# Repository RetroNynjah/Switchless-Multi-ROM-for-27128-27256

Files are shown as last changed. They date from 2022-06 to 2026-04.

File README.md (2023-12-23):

# Switchless Multi-ROM for 27128 & 27256 ROMs

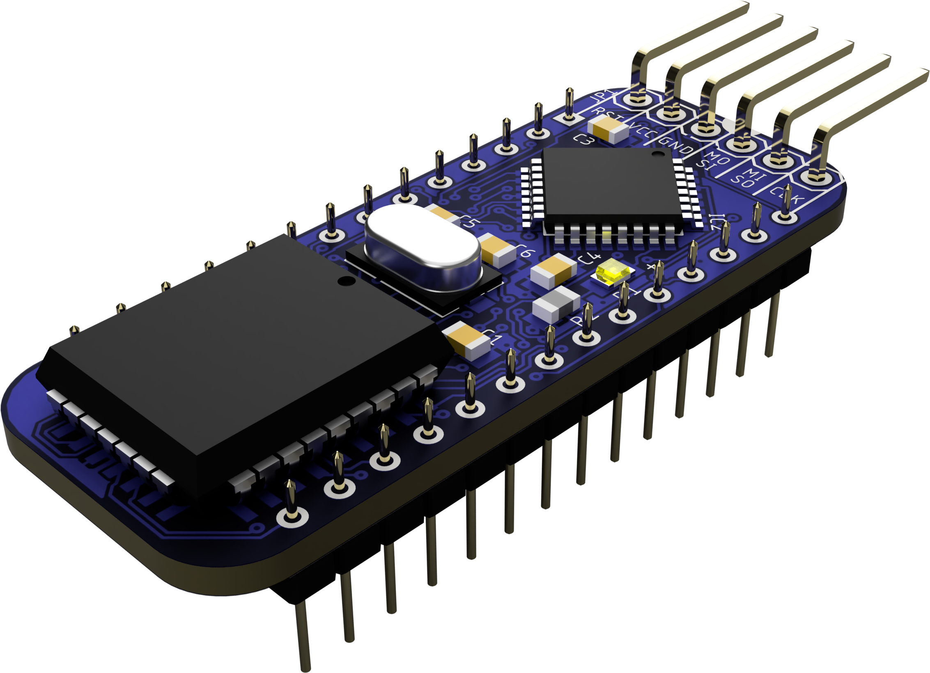
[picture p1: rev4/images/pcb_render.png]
3D rendering
<br/>

A switchless multi-ROM for 27128 and 27256 ROM (28-pin) type applications. The switch is controlled by an MCU that is picking up predefined magic words on the data bus.  
This is a more generic and further developed version of my previous 1541-II Multi-ROM design.

Example use cases:
* ROM switch for Commodore disk drives controlled by DOS commands.
* Menu driven Kernal switch for Commodore C64 (shortboards), Commodore C128 and Commodore TED series.
* You tell me

Check the Applications folder for examples on how to use it for the use cases above.

Check the Technical Guide for a general technical description, build instructions and BOM.

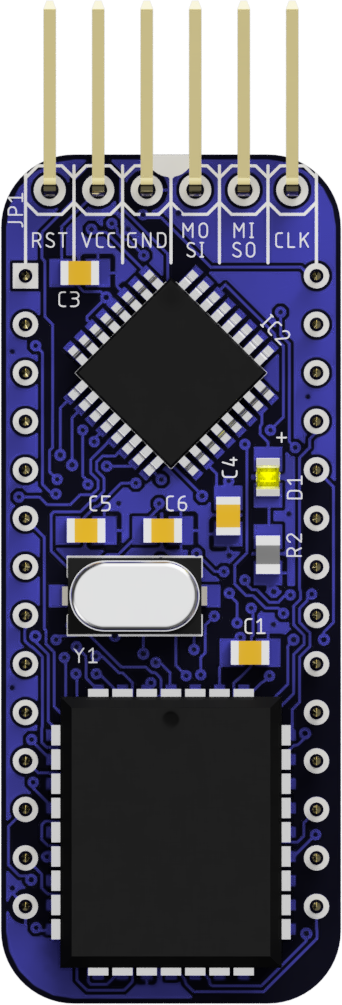
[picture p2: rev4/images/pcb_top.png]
Rendered top view
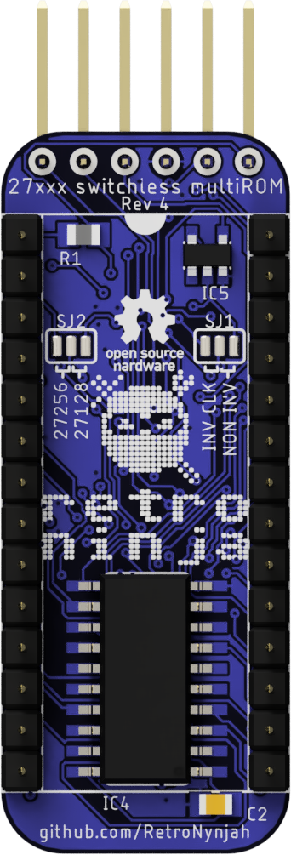
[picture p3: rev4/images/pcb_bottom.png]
Rendered bottom view
  <br/>

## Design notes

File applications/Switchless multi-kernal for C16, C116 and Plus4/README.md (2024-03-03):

# Switchless multi-kernal for Commodore Plus/4 and C16

Can be used as a Kernal switch for the Commodore Plus/4 and C16. It hasn't been tested but could possibly work with the C116 too. 
The Kernal menu is activated by holding the reset switch for a few seconds and then releasing it.

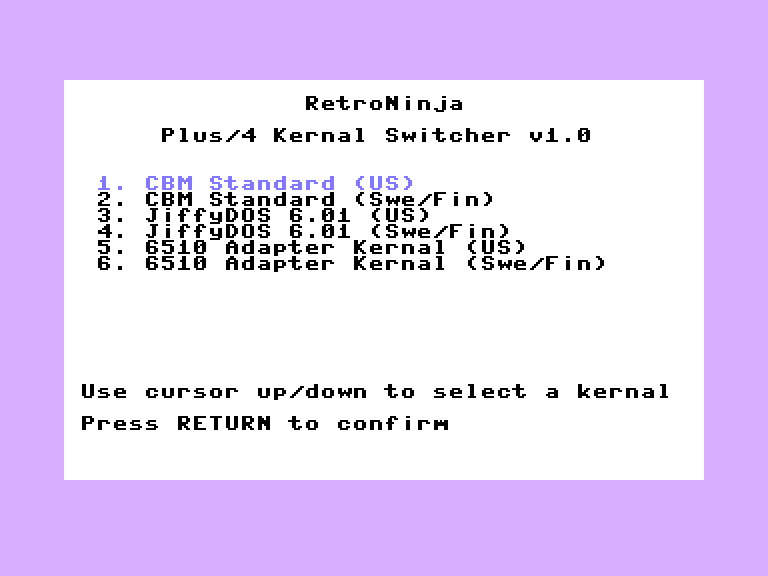
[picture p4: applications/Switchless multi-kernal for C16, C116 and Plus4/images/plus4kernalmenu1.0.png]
Plus/4 Kernal menu screenshot
<br/>

Read more in the User's Guide

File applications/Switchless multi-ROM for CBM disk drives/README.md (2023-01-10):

# Switchless multi-ROM for CBM 1541-II, 1571 and 1581
Switches DOS ROM on Commodore IEC drives that uses 27128/27256 ROMs.  
Can be used to switch ROM between CBM DOS/JiffyDOS/SpeedDOS/DolphinDOS and so on.  
Has been tested in 1541-II, 1571, 1581 and Enhancer 2000 but should work in other 1-2MHz drives with 28-pin ROM.

The switch is controlled by sending a command like *LOAD "2@RNROM",8* from the computer to switch to drive ROM image 2.  
Using a JiffyDOS Kernal a command like *@2@RNROM* can also be used.

Read more in the User's guide.

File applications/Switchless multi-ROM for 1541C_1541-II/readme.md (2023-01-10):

The contents of this folder has been moved to https://github.com/RetroNynjah/Switchless-Multi-ROM-for-27128-27256/tree/main/applications/Switchless%20multi-ROM%20for%20CBM%20disk%20drives

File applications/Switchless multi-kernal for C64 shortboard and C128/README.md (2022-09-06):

# Switchless multi-kernal for C64 shortboard and C128

Can be used as a Kernal switch for the C64 shortboard motherboards and the C128. It has not been tested with C128CR/DCR but works well ion C128/C128D.
The Kernal menu is activated by pressing the RESTORE key for a few seconds (CBM+RESTORE for C64 part Kernal switch in a C128/C128D).

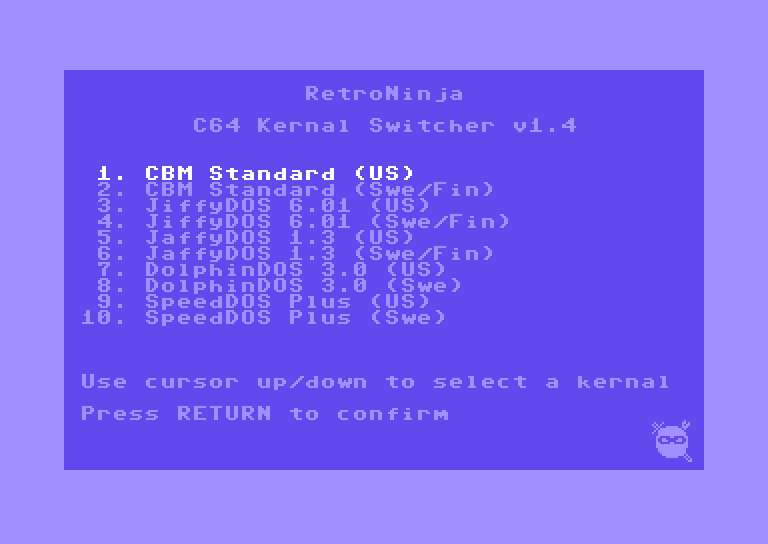
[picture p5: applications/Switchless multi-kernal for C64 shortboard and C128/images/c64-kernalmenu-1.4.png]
C64 Kernal menu
<br/>
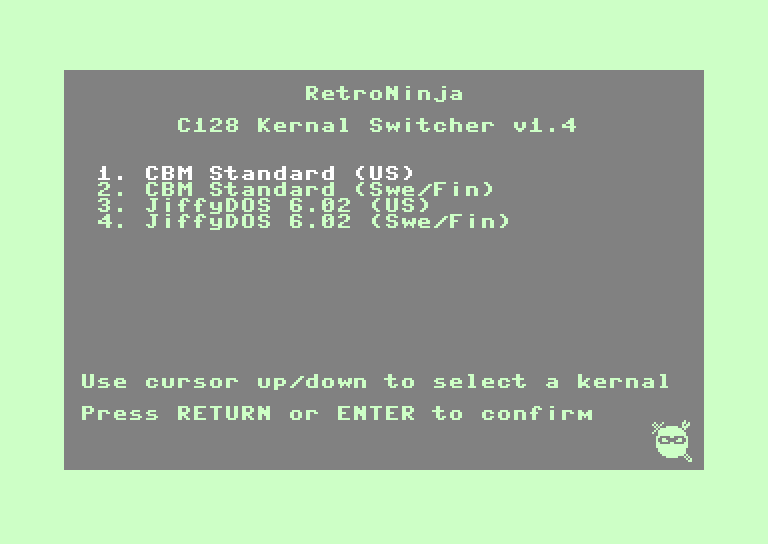
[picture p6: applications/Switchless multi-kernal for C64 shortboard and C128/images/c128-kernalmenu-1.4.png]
C128 Kernal menu
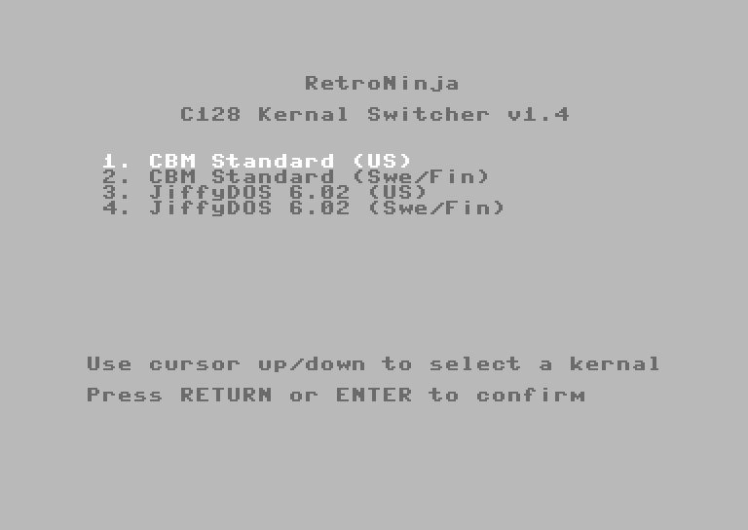
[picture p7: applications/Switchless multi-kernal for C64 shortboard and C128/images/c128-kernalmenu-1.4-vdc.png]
C128 VDC Kernal menu
<br/>

Read more in the User's Guide

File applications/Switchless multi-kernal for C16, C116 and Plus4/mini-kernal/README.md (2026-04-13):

# Plus/4 Mini-Kernal

This is the assembly source code for the C16/C116/Plus4 mini-Kernal.
The projects were created in CBM prg Studio. It needs to be built specifically for PAL or NTSC systems although it has only been tested with PAL systems.

You need to adjust the menu to fit your needs and compile the Mini-Kernals yourself unless you are going with the exact same Kernals I did.

## Disclaimer:  
I'm not an assembly programmer which you should be able to tell by looking at the source. If the code doesn't work for you feel free to fix it,
If anyone wants to have a go at improving and optimizing the code you are free to do so too.

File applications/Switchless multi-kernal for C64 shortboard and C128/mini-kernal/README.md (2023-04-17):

# C64 and C128 Mini-Kernals

This is the assembly source code for the C64 and C128 Mini-Kernals.
The projects were created in CBM prg Studio. They should work with both PAL and NTSC systems although only the C128 version has been tested with NTSC.

You need to adjust the menu to fit your needs and compile the Mini-Kernals yourself unless you are going with the exact same Kernals I did.

## Disclaimer:  
I'm not an assembly programmer which you should be able to tell by looking at the source. If the code doesn't work for you feel free to fix it,
If anyone wants to have a go at improving and optimizing the code you are free to do so too.

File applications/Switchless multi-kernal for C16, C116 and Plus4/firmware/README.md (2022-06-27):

# Firmware

The firmware directories contains source code along with some precompiled hex files for the microcontroller.

The source code is written using the Arduino environment and can be flashed directly from Arduino using an ISP programmer.

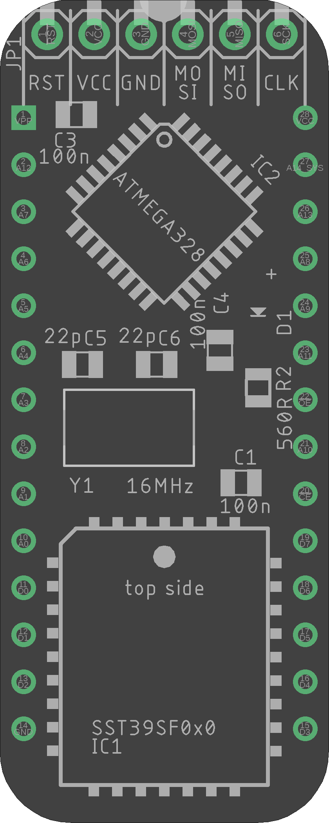
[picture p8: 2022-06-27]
rev4/images/place-top-crop.png

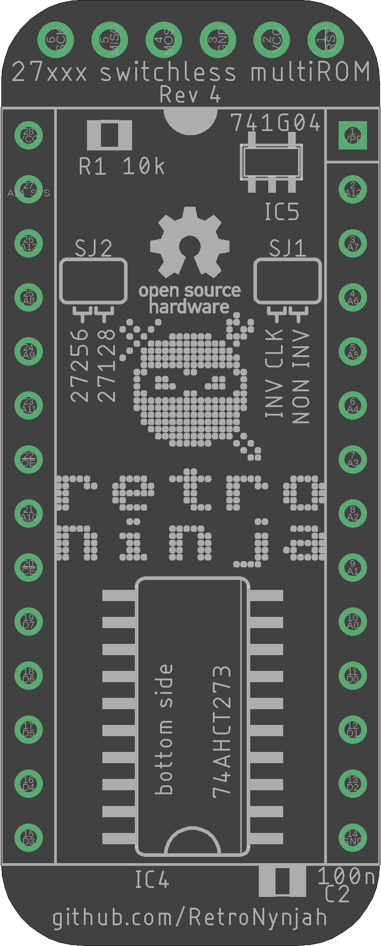
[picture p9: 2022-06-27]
rev4/images/place-bottom-crop.png

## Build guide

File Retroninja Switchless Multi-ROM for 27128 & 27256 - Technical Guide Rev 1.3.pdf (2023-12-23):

# Retroninja Switchless Multi-ROM for 27128

& 27256

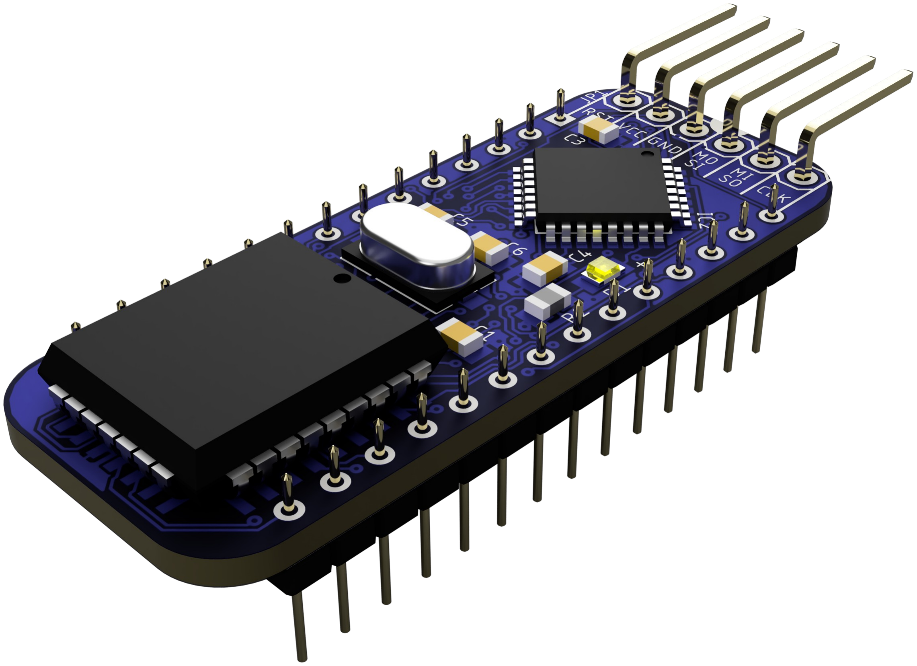
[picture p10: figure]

# Technical Guide

Retroninja Switchless Multi-ROM for 27128 & 27256 | Technical Guide Version 1.3

## Table of Contents

# Background

I first created this ROM switcher as a DOS ROM switcher for the Commodore 1541-II disk drive which uses a 27128 compatible ROM. The space in the 1541-II is very limited. That's why the module is so small and has to use SMD components.
I realized that it can be used for a lot of other equipment that is using similar ROMs so it was re-branded and upgraded to support switching 27256 ROM images too.

# Theory of operation

The circuit is meant to sit in a ROM socket instead of a 28-pin 27128/27256 ROM.
The AVR microcontroller (MCU) is connected to the data pins of the ROM socket through a flip-flop that latches the data to give the MCU more time to read the data. It's also connected to some header pins that can be connected to a clock source, a reset line and optionally other signals. It also has an on-board flash chip that contains multiple ROM images.
With the help of an external clock source, the MCU can capture bytes that are passing on the data bus and react to a predefined string of ”magic bytes” by switching the upper address pins on the flash circuit to switch to a different ROM image.
The flip-flop triggers on positive-edge of clock and if data is arriving on the bus at the negative edge of the clock signal then the clock source needs to be inverted for the flip-flop to latch the data correctly. This can be done by installing the inverter gate at IC5 and configuring solder jumper SJ1 for inverted clock.
The need for this differs between implementations depending on how the magic bytes ends up on the bus. The module has two modes: 27128 and 27256 mode. The mode is selected using a solder jumper. In 27128 mode the A14 address pin on the flash chip is controlled by the MCU giving the MCU five address pins (A14-A18) to use which gives a maximum of 32*16KByte ROMs. In 27256 mode the A14 pin is controlled by the host system leaving four address pins (A15-A18) to the MCU which gives a maximum of 16*32KByte ROMs. An onboard LED can be used for diagnostic blinking or other feedback.

# Usage examples

The two use cases I've used it in is for switching JiffyDOS ROM in Commodore disk drives and Kernal in the Commodore 8-bit computers but it should be usable for other things too.

Commodore 1541-II/1571/1581 DOS ROM Switcher
The MCU source code for the 1541-II/1571/1581 ROM switch can be found under applications in the GitHub repository: https://github.com/RetroNynjah/Switchless-Multi-ROM-for-27128-27256
At power on, the MCU in the ROM switcher reads address 0 from its internal EPROM to find out which ROM it should select, sets the A14-A18 (or A15-A18) address pins on the flash chip accordingly and resets the drive to make sure it’s booted with the correct image. This can be noticed when the drive is powered on and the drive initializes and stops spinning and then spins up again briefly during the switch reset.
It then starts listening for a switch command.
Even at a clock speed of 20 MHz, reading and analyzing data on a 1-2MHz data bus can be quite a challenge so the data on the drive data bus is buffered in the switcher by a 74AHCT273 flip-flop that is clocked by the Write signal on the 6502 MPU in the drive. By clocking the data with the R/W signal we filter out irrelevant bus traffic and the flip-flop holds the relevant data until the next R/W cycle. This gives the MCU a little more time to read the data from the flip-flop.

The MCU listens for a predefined sequence of bytes in reverse order (MORNR@) and once the sequence is found, it treats the following numeric character as the target ROM image number. The reverse order of the characters on the bus is why the image number must be specified at the beginning of the command.
The MCU sets address pins A14-A18 (or A15-A18) on the flash chip according to image selection and it stores the ROM number at address 0 of its internal EPROM for use at next power-on. It then resets the drive by toggling the reset line.
The command can be sent from basic on a computer such as C64 or C128 by utilizing any disk drive command that contains text strings such as:

If the computer is equipped with JiffyDOS and the correct drive has been selected using CTRL-D or similar, DOS wedge commands can be used for switching ROM:

The commands in the above examples will return a file not found error but you should see the drive switch ROM and perform a drive reset and turn of the error LED. The ROM switch LED will blink 2 times to indicate that image 2 was selected.
When building a 1541-II ROM switch you should bridge the solder jumpers like this:
SJ1
Inverted Clock | Non-inverted Clock

Note: To invert clock we must also install IC5

SJ2
27256 | 27128

And for a 1571 and 1581 ROM switch the solder jumpers should be configured like this: SJ1
Inverted Clock | Non-inverted Clock

Note: To invert clock we must also install IC5

SJ2
27256 | 27128

Some pins on the switch needs to be connected to the right signals in the drive. These signals can be connected to the drive using test clips but to have a secure installation it's better to solder the cables to the bottom of the PCB.

LOAD “2@RNROM”,8

@2@RNROM

Switch pin | Drive signal
CLK | R/W (6502 pin 34)
MOSI | RESET (Middle pin of IEC DIN connector)

This switch only suits the 1541-II/1571/1581 and clones that has 28-pin ROM sockets.
1541 drives and some of it's clones have 24-pin 2364 type ROMs and I have another Multi-ROM version that is compatible with those in the following repository: https://github.com/RetroNynjah/Switchless-Multi-ROM-for-2364

Commodore 64 shortboard/C128/TED series menu-driven Kernal switch
The MCU source code and Mini-Kernal source code for the C64 shortboard/C128 kernal switch can be found under samples in the GitHub repository at: https://github.com/RetroNynjah/Switchless-Multi-ROM-for-27128-27256
At power on, the MCU in the Kernal switch reads address 0 from its internal EPROM to find out which Kernal it should select, sets the A14-A18 (or A15-A18) address pins on the flash chip accordingly and resets the drive to make sure it’s booted with the correct image.
If at any time, restore is pressed and held for a few seconds the MCU will detect this and switch to Kernal 0 which is a menu Kernal. The C16/116/Plus4 menu is activated by holding RESET for a few seconds and then releasing it.
For this application I created custom Mini-Kernals for the C64, the C128 and the C16/C116/Plus4 that display lists of Kernals to choose from.

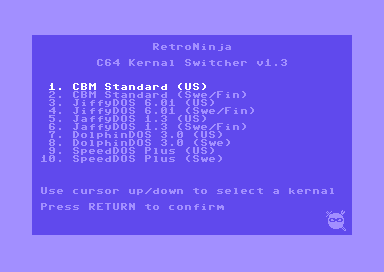
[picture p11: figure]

When the user selects a Kernal image from the menu, the Mini-Kernal writes a predefined switching command to RAM along with a byte that indicates the selected image number. It does this over and over. Example of the command: RNROM64#1, RNROM128#1 or RNROM+4#1 where 1 is a byte with value 0x01 that tells the switch that we want to switch to kernal image 1.
The Kernal switch now captures the command from the data bus, writes the selected kernal number to the MCU EPROM for future use, then it switches the address pins A14/A15-A18 accordingly. It then pulls the reset line briefly to make the computer restart using the new Kernal. The computer will continue to start up using this Kernal until a new choice is made.
Having different commands for the platforms makes it possible to equip both the ROM sockets in a Commodore 128 (not CR/DCR) with Kernal switches and keep them separated.

In this case both switches will trigger their menus when RESTORE is held as the MCUs don't know if they are being addressed or not. The MCUs will switch back to the previous image if they detect that a reset is being performed by something other than themselves.
To activate the C64 switch menu in a C128 you hold the CBM key together with RESTORE. When selecting an image from the C64 kernal menu you hold CBM while you press RETURN to make it boot into C64 mode with the new Kernal.
The C128CR/DCR doesn't have a separate ROM for the C64 part and doesn't need an separate switch for C64 mode but it needs to have the C64 Basic and Kernal images bundled in the same flash ROM as the C128 Kernals. This switch will switches Kernals for both C64 mode and C128 mode at the same time. This can be both good or bad depending on how you combine your Kernals.
It also needs to have the Mini-Kernals modified so that both Mini-Kernals uses the same switching
command such as RNROMDCR#1 and have an MCU firmware compatible with 27256 switching.
For the C128, the flash is populated with a 16 KB C128 Mini-Kernal followed by up to 31*16 KB Kernals (good luck finding more than a couple).

For the C64, the flash is populated with a 16 KB combination of 8 KB basic ROM and 8 KB Mini-Kernal followed by up to 31*16 KB Basic+Kernal combinations.
Here's an example ROM layout for a C64 shortboard or the C64 Kernal in the C128 that fits an SST39SF010A:

Example for a C128 with an SST39SF010A:

Example for a C128CR/DCR with an SST39SF010A:

As both C64 mode and C128 mode Kernals are in the same ROM a larger flash chip may be needed to accommodate all Kernals. If you have more C64 Kernals than C128 Kernals you still need to fill the vacant C128 slots with working Kernals such as a stock CBM Kernal or you will never be able to start the C128 into C64 mode either.
When building a C64/C128/TED-series Kernal switch you should bridge the solder jumpers like this:
SJ1
Inverted Clock | Non-inverted Clock

Note: As we don't invert the clock we don't need to install IC5 either

SJ2 (all except CR/DCR)
27256 | 27128

SJ2 (C128CR/DCR)
27256 | 27128
C64 Basic | 64 Mini | 128 Mini | C64 Basic | 64 CBM krnl | 128 CBM krnl | C64 Basic | 64 Jiffy US | 128 Jiffy US | C64 Basic | 64 Jiffy SE | 128 Jiffy SE
8kB | 8kB | | 8kB | 8kB | | 8kB | 8kB | | 8kB | 8kB
16kB | | 16kB | 16kB | | 16kB | 16kB | | 16kB | 16kB | | 16kB
Mini-Kernal | CBM Kernal | JiffyDOS US | JiffyDOS SE | JiffyDOS DK | Mini-Kernal | Mini-Kernal | Mini-Kernal
16kB | 16kB | 16kB | 16kB | 16kB | 16kB | 16kB | 16kB
Basic | Mini-Kernal | Basic | CBM Kernal | Basic | JiffyDOS US | Basic | JiffyDOS SE | Basic | JiffyDOS DK | Basic | JaffyDOS | Basic | DolphinDOS | Basic | SpeedDOS
8kB | 8kB | 8kB | 8kB | 8kB | 8kB | 8kB | 8kB | 8kB | 8kB | 8kB | 8kB | 8kB | 8kB | 8kB | 8kB
16kB | | 16kB | | 16kB | | 16kB | | 16kB | | 16kB | | 16kB | | 16kB

Some pins on the switch needs to be connected to the right signals in the computer. These signals can be connected to various ICs in the computer using test clips but to have a secure installation it's better to solder the cables to vias on the PCB. See pictures in the samples directory of the GitHub repository.
Switch pin | Computer signal | Comments
CLK | R/W
MISO | RESTORE | Only on C64/C128
MOSI | RESET

When building a Kernal switch for the Plus/4 (or C116) you will need to keep the profile low by using the flat kind of headers that are usually sold as “Stackable Arduino headers”.

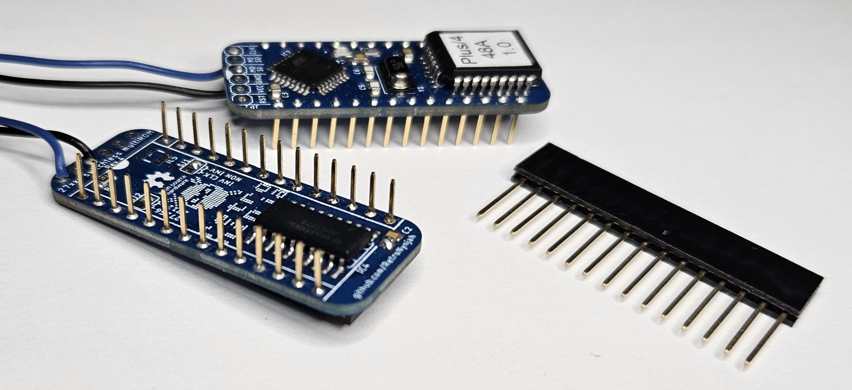
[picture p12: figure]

Optionally you can remove the Kernal socket and solder the switch directly to the motherboard using any kind of header.
This switch when configured as a C64 Kernal switch fits the C64 shortboard (PCB 250469) and the C64 part of the C128. C64 longboards have 24-pin 2364 type Kernal ROMs and I have another Multi-ROM version that is compatible with those in the following repository: https://github.com/RetroNynjah/Switchless-Multi-ROM-for-2364

# Assembling the module

The PCB is small and a bit difficult to solder but it can be hand soldered. The reason for the small size is space constraints in the Commodore 1541-II disk drives that this PCB was initially designed for. Other drives such as 1571 and 1581 have the same constraints.
The flash chip (PLCC) is the trickiest part to solder and I recommended reflow soldering the top side using stencil and solder paste. Then solder the bottom side by hand and finally solder the pin headers.
There are two solder jumpers on the bottom that must be configured.
If you configure SJ1 for inverted clock then you must also install IC5. Otherwise you can leave it out. It will only be used when SJ1 is configured for inverted clock.
Note: Don't forget to program the flash before soldering!

# Parts

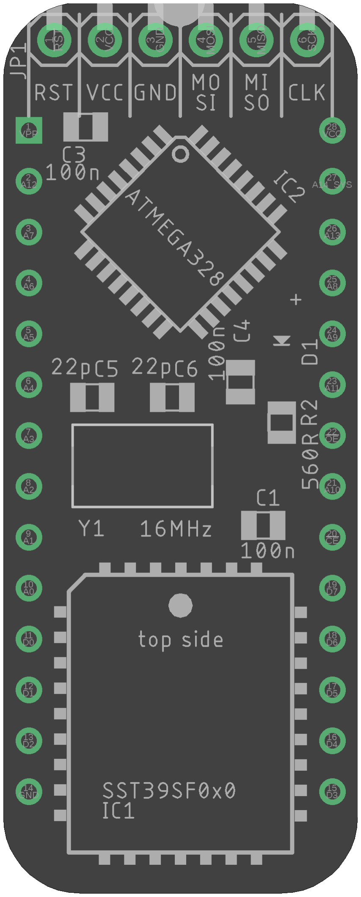
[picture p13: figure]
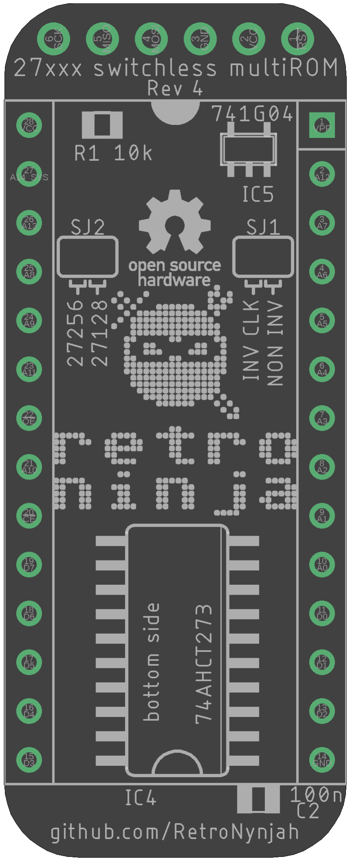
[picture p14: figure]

Top side is to the left, bottom side is to the right.
Component | Part | Description | Comment
JP1 | Header | 6-pin right-angle
D1 | LED | 0805 LED
C1, C2, C3,C4 | 100nF capacitor | 0805 ceramic
C5, C6 | 30pF capacitor | 0805 ceramic | 22pF works fine too
Y1 | ECS-200-20-3X-TR | 20MHz Crystal | 16MHz is ok for 1MHz systems
R1 | 10kΩ resistor | 0805 Resistor
R2 | 560Ω resistor | 0805 Resistor
IC1 | SST39SF0x0 | 32-PLCC Flash 4.5-5.5V | SST39SF010/20/40
IC2 | ATmega MCU | 32-TQFP MCU | Atmega48/88/168/328
IC3 | Headers | 2 header rows, 14 pin | Use machined or flat pins - not square
IC4 | 74AHCT273 | 20-SOIC 5.3mm Flip-Flop
IC5 | 741G04 | SOT23-5 1 x Inverter | Only needed if clock needs inverting
The ATmega model is not critical. The firmware requires less than 2KB of MCU flash. I have tested Atmega48, 48A, 48PA, 48PB, 88A, 328P and they have worked for me. Any other pin-compatible ATmega could work too depending on your application but it must be able to run at 20MHz if you are going to use it in a 2MHz system such as 1571/1581. For 1MHz systems it is enough with 16MHz.

# Programming the microcontroller

The firmware can be flashed using the 6-pin ISP header. The source code is written for Arduino and programming the firmware can be done directly from the Arduino IDE using an ISP programmer.
If you are using an Atmega328 it can be programmed as an Arduino UNO. The other variants require custom board definitions. I recommend the DIY AVR cores that can be installed using the Arduino Boards Manager (https://github.com/sleemanj/optiboot).
If you can't or don't want to use Arduino I have some pre-compiled hex files for the Kernal switch and drive ROM switch along with fuse configurations and syntax examples for how to program them using avrdude. These can be found under the Applications folder in my GitHub repository.

# Programming the flash chip (ROM)

The flash chip needs to be programmed before soldering it. If you need to reprogram the flash later it must first be de-soldered and then re-soldered again after reprogramming.
You need to concatenate all your images into one file and fill up any empty space in flash with valid extra images to avoid bricking your host device if an incorrect image number is selected. If that would happen the EPROM can be reset by re-flashing the firmware.
In 27128 mode all images should be 16KB and in 27256 mode all the images need to be 32KB.

# Document revision history

1.0 Initial version
1.1 BOM Corrected
1.2 Updated BOM with 20MHz crystal, changed AVR core and added information about 1571 & 1581 1.3 Updated kernal switch section with C16, C116 and Plus/4

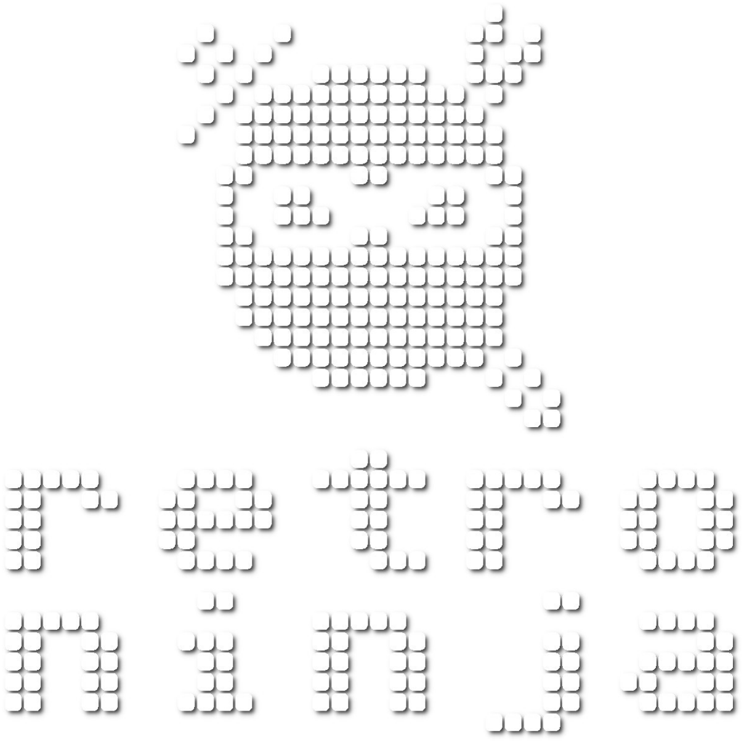
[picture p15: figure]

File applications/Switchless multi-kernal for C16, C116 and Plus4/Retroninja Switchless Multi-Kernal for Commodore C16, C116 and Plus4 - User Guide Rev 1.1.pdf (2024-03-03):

# Retroninja Switchless Multi-Kernal for Commodore C16, C116 & Plus/4


# User Guide

Retroninja Switchless Multi-Kernal for Commodore C16, C116 & Plus/4

User Guide
Version 1.1

## Table of Contents

# Functional description

At power on, the MCU in the Kernal switch holds the reset line active while it reads address 0 from its internal EPROM to find out which Kernal it should select, sets the A14-A18 address pins on the flash chip accordingly and releases the reset line to make sure the computer is booted using the correct Kernal.
If at any time, reset is pressed and held for a few seconds the MCU will detect this and switch to the first Kernal in ROM (Kernal 0) which is a menu Kernal. For this application I created a custom Mini-Kernal for the C16/C116/Plus4 that displays a list of Kernals to choose from.

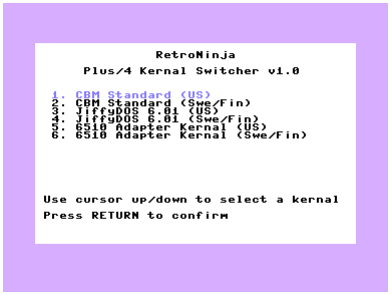
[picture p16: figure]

When the user selects a Kernal image from the menu, the Mini-Kernal writes a predefined switching command to RAM along with a byte that indicates the selected image number. It does this over and over. Example of the command: RNROM+4#1 where 1 is a byte with value 0x01 that tells the switch that we want to switch to Kernal image 1.
The Kernal switch now captures the command from the data bus, writes the selected Kernal number to the MCU EEPROM for future use, then it switches the ROM address pins A13-A18 accordingly. Finally, it resets the computer using the new Kernal by pulling the reset line briefly. The computer will continue to start up using this new Kernal until a new choice is made.
The flash is populated with the Mini-Kernal followed by up to 10*16kB Kernals. It would in theory be possible to add up to 31 Kernals if both the Mini-Kernal and the MCU firmware was modified in some way to accommodate that many Kernal images.
Here's an example layout that fits in an SST39SF010A:
Mini-Kernal | CBM EN | CBM Swe | Jiffy En | Jiffy Swe | 6510 En | 6510 Swe | blank
16kB | 16kB | 16kB | 16kB | 16kB | 16kB | 16kB | 16kB

# Installing the Kernal switch

The switch will replace the Kernal ROM chip (U24 on the Plus/4 or U4 on C16/C116).
Pay attention to the direction of the notch on the chip that indicates the location of pin 1. Pin one on the switch should face the same direction. Pin 1 on the switch is at the end that has a 6-pin header. It is also indicated by a printed notch on the bottom side of the switch.
The switch needs low profile pin headers to fit in the Plus/4 or the socket might need to be removed from the motherboard so the switch can be soldered directly to the board.
The below pins on the switch must be connected to the right signals on the motherboard.
Switch pin | Computer signal | Example of locations
CLK | R/W | 7501/8501 pin 39, 6529 pin 1
MOSI | RESET | 7501/8501 pin 40, 7551/8551 pin 4

The connections can be made on the chips using test clips but it's recommended to solder pin headers to vias on the motherboard where available and connect the pin headers using Dupont wires or solder a cable to the motherboard for a permanent installation. If you want to solder pin headers to the vias you can try inserting them from the top side without taking the board out. Try heating the pins with the soldering iron while pushing them into the via using pliers but to get the best possible connection of the pins they should be soldered from the bottom of the motherboard.
The below pictures show examples of suitable vias for different motherboards.

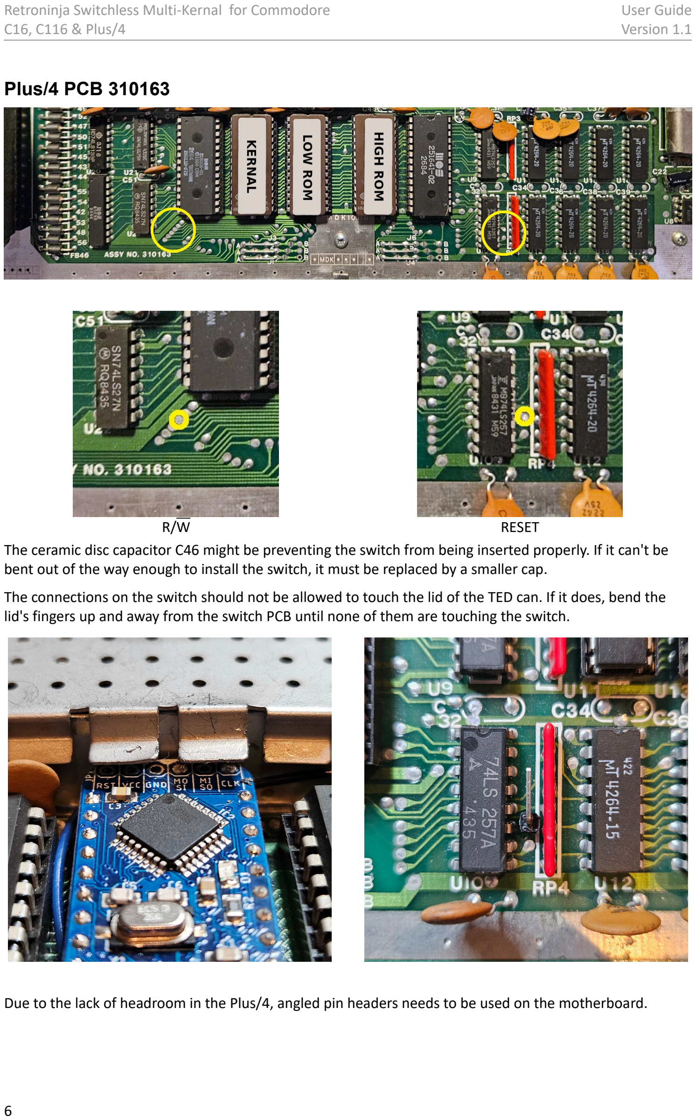
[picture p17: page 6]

Plus/4 PCB 310163

R/W | RESET
The ceramic disc capacitor C46 might be preventing the switch from being inserted properly. If it can't be bent out of the way enough to install the switch, it must be replaced by a smaller cap.
The connections on the switch should not be allowed to touch the lid of the TED can. If it does, bend the lid's fingers up and away from the switch PCB until none of them are touching the switch.

Due to the lack of headroom in the Plus/4, angled pin headers needs to be used on the motherboard.

C16

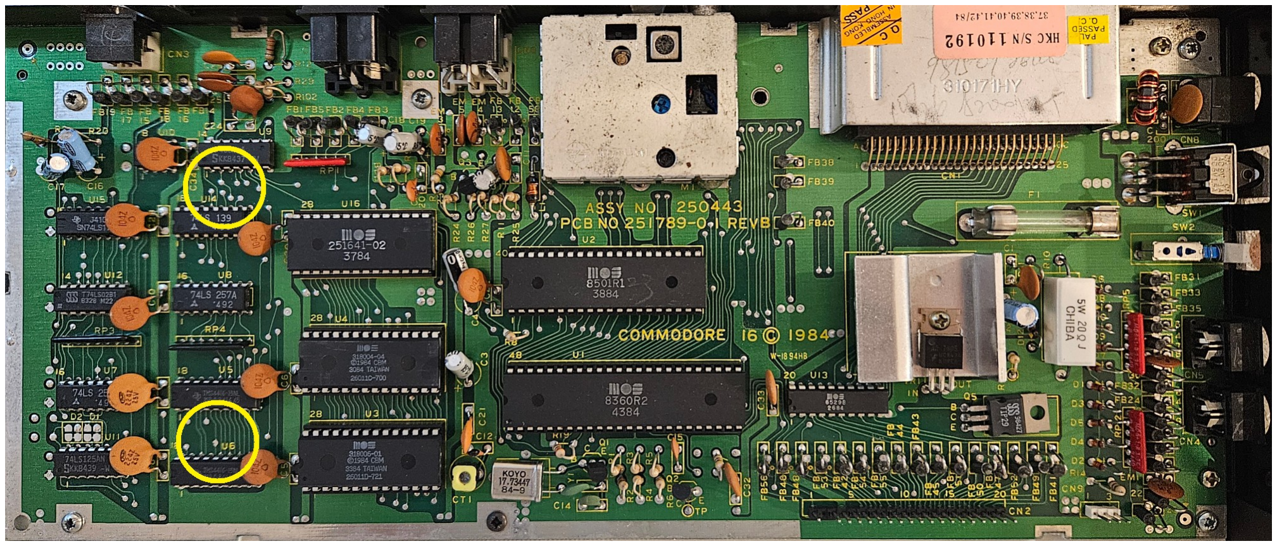
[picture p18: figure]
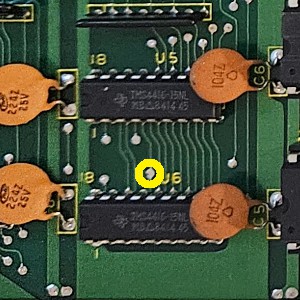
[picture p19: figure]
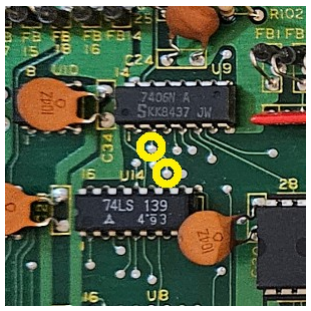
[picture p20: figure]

R/W | RESET

C116
TBD

# Using the Kernal switch

Hold the reset key for about three seconds and then release it to activate the Kernal menu. Once in menu you can use cursor up/down to move to the Kernal you want to switch to and press return. The switch resets the computer with the new Kernal and saves your choice for next power-on.

# Upgrading the firmware

The firmware in the microcontroller can be upgraded using the 6 ISP pins. The source code is written for Arduino and programming the firmware can be done directly from the Arduino IDE using an ISP programmer.

If your device is using an Atmega328 it can be programmed as an Arduino UNO. The other variants require custom board definitions. I have used the Easy DIY AVR cores from https://github.com/sleemanj/optiboot. Board manager URL is
https://raw.githubusercontent.com/sleemanj/optiboot/master/dists/package_gogo_diy_atmega8_series_in dex.json (https://raw.githubusercontent.com/sleemanj/optiboot/master/dists/package_gogo_diy_atmega8_series_index.json)
If you can't or don't want to use Arduino I have some precompiled hex files for the Kernal switch and drive ROM switch along with fuse configurations and syntax examples for how to program them using avrdude. These can be found under the Applications folder in my GitHub repository at: https://github.com/RetroNynjah/Switchless-Multi-ROM-for-27128-27256

# Programming the flash chip (ROM)

The flash chip needs to be programmed before soldering it. If you need to reprogram the flash later it must first be desoldered and then resoldered again after reprogramming.
The flash chip should contain the Mini-Kernal image followed by all switchable kernal images in correct order. All images needs to have a size of exactly 16kB.

# Document revision history

1.0 Initial version
1.1 Added C16 pictures

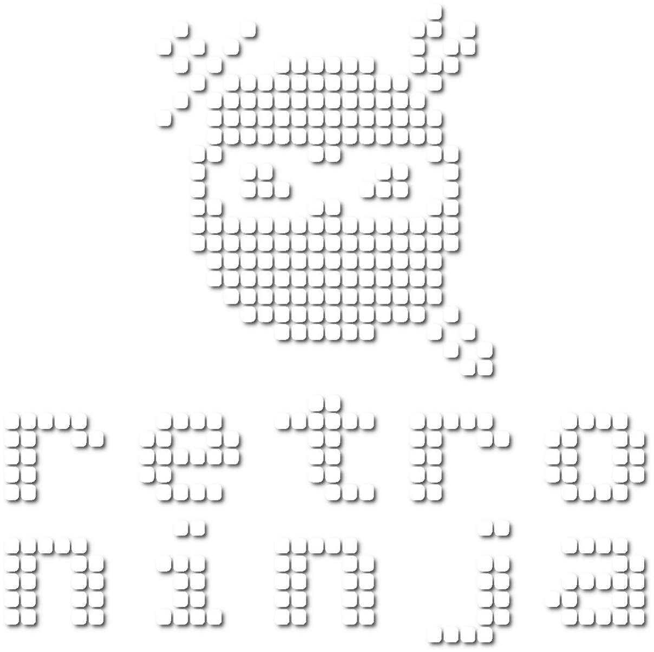
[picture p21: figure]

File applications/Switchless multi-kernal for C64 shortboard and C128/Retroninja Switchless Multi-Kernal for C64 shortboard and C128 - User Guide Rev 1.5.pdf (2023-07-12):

# Retroninja Switchless Multi-Kernal for C64 shortboard and C128

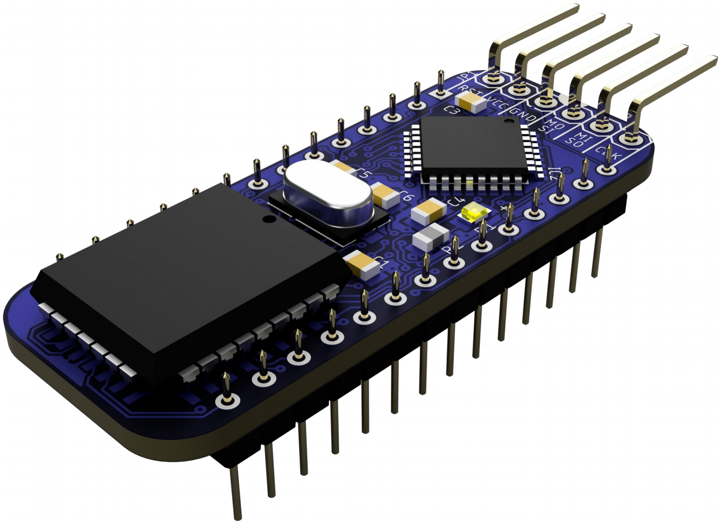
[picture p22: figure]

# User Guide

Retroninja Switchless Multi-Kernal for C64 shortboard and C128

User Guide
Version 1.5

## Table of Contents

# Functional description

At power on, the MCU in the Kernal switch holds the reset line active while it reads address 0 from its internal EPROM to find out which Kernal it should select, sets the A14-A18 address pins on the flash chip accordingly and releases the reset line to make sure the computer is booted using the correct Kernal.
If at any time, restore is pressed and held for a few seconds the MCU will detect this and switch to Kernal 0 which is a menu Kernal. For this application I created custom Mini-Kernals for the C64 and the C128 that displays a list of Kernals to choose from.


When the user selects a Kernal image from the menu, the Mini-Kernal writes a predefined switching command to RAM along with a byte that indicates the selected image number. It does this over and over. Example of the command: RNROM64#1 where 1 is a byte with value 0x01 that tells the switch that we want to switch to kernal image 1.
The Kernal switch now captures the command from the data bus, writes the selected kernal number to the MCU EPROM for future use, then it switches the address pins A14-A18 accordingly. It then resets the computer using the new Kernal by pulling the reset line. The computer will continue to start up using this new Kernal until a new choice is made.
The flash is populated with the Mini-Kernal followed by up to 10*16 KB Kernals. It would in theory be possible to add up to 31 Kernals if both the Mini-Kernal and the MCU firmware was modified in some way to accommodate that many Kernal images.
Here's an example for a C64 layout that fills out an SST39SF010A:

Example for C128 with an SST39SF010A:

Example for C128DCR with an SST39SF010A:

As both C64 mode and C128 mode Kernals are in the same ROM a larger flash chip may be needed to accommodate all Kernals. If you have more C64 Kernals than C128 Kernals you still need to fill the C128 slots with working Kernals such as a stock CBM kernal or you will never be able to start the C128 into C64 mode either.

Basic | Mini-Kernal | Basic | CBM Kernal | Basic | JiffyDOS US | Basic | JiffyDOS SE | Basic | JiffyDOS DK | Basic | JaffyDOS | Basic | DolphinDOS | Basic | SpeedDOS
8kB | 8kB | 8kB | 8kB | 8kB | 8kB | 8kB | 8kB | 8kB | 8kB | 8kB | 8kB | 8kB | 8kB | 8kB | 8kB
16kB | | 16kB | | 16kB | | 16kB | | 16kB | | 16kB | | 16kB | | 16kB
Mini-Kernal | CBM Kernal | JiffyDOS US | JiffyDOS SE | JiffyDOS DK | Mini-Kernal | Mini-Kernal | Mini-Kernal
16kB | 16kB | 16kB | 16kB | 16kB | 16kB | 16kB | 16kB
C64 Basic | 64 Mini | 128 Mini | C64 Basic | 64 CBM krnl | 128 CBM krnl | C64 Basic | 64 Jiffy US | 128 Jiffy US | C64 Basic | 64 Jiffy SE | 128 Jiffy SE
8kB | 8kB | | 8kB | 8kB | | 8kB | 8kB | | 8kB | 8kB
16kB | | 16kB | 16kB | | 16kB | 16kB | | 16kB | 16kB | | 16kB

The C64 version of this Kernal switch only suits the C64 shortboards (PCB 250469) and the C64 part of the C128.
The C128DCR doesn't have a separate ROM for the C64 part and doesn't need an separate switch for C64 mode but it needs a specially combined DCR version of this switch.
C64 longboards have 24-pin 2364 type Kernal ROMs and I have another Multi-ROM version that is compatible with those at:
https://github.com/RetroNynjah/Switchless-Multi-ROM-for-2364

# Installing the Kernal switch

The below pins on the switch must be connected to the right signals on the C64 motherboard.
Switch pin | Computer signal | Example of locations
CLK | R/W | 8500 pin 38, 6526 pin 22
MISO | RESTORE | KBD connector pin 3
MOSI | RESET | 8500 pin 40, 6526 pin 34

The signals can be found at the below places on the C128 motherboard.
Switch pin | Computer signal | Example of locations
CLK | R/W | 8502 pin 39, 8563 pin 9, 6526 pin 22
MISO | RESTORE | KBD connector pin 3, U16 pin 9
MOSI | RESET | 8502 pin 40, 6526 pin 34

The connections can be made on the chips using test clips but it's recommended to solder pin headers to vias on the motherboard and connect to the pin headers using Dupont wires or solder one end of Dupont cables directly to the vias for a permanent installation.
If you want to solder pin headers to the vias you can try inserting them from the top side without taking the board out. Try heating the pins with the soldering iron while pushing them into the via using pliers but to get the best possible connection of the pins they should be soldered from the bottom of the motherboard. The following pages show where the switch should be installed and shows examples of suitable vias for different motherboards.

C64 PCB 250469
The switch will replace Kernal ROM chip named U4 on this board. U4 is normally not socketed and needs to be desoldered from the board and replaced with a socket before the switch is installed.
Pay attention to the notch on the ROM chip U4 indicating pin 1. The socket should have it's notch facing the same direction and the switch should also be installed with pin 1 facing the same direction.
Pin 1 on the switch is at the end that has six header pins. It is also indicated by a printed notch on the bottom side of the board.

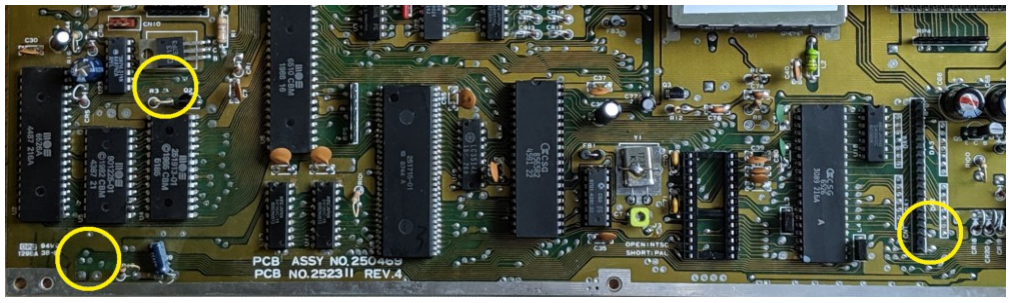
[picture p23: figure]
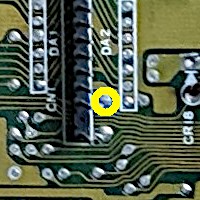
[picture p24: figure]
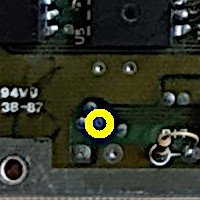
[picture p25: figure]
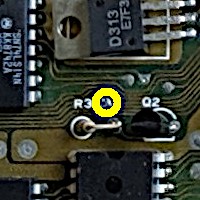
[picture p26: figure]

RESTORE | R/W | RESET

C128/C128D
This board requires two switches. The switch for C128 will replace the C128 Kernal ROM named U35 and the C64 mode switch replaces the C64 Kernal ROM U32.
Pay attention to the notch on the socket that indicates pin 1. Pin 1 on the switch is at the end that has six header pins. It is also indicated by a printed notch on the bottom side of the board.
The R/W signal in the point marked below can be a bit low on some C128s such as the Rev 7 boards and on the C128 Neo. If you can't get the switch to switch kernal after selecting an image (hangs on selection), try connecting to the R/W signal on the 8563 or 8502 instead to see if that makes a difference. See page 6 for connection points.

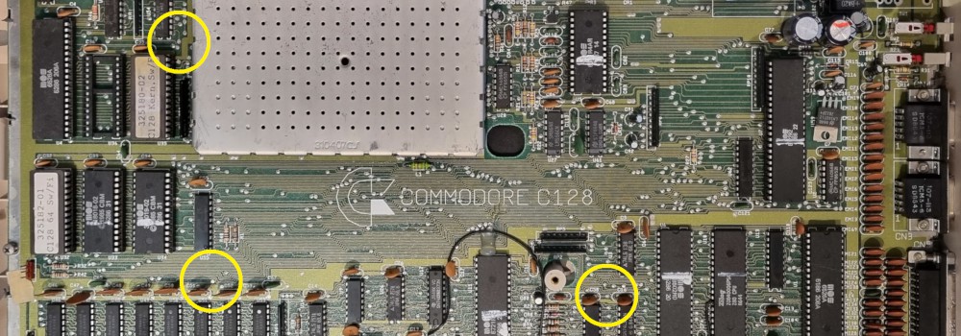
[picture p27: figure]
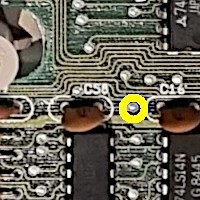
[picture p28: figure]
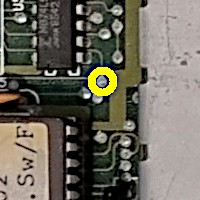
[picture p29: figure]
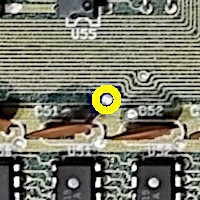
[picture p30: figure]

RESTORE | R/W | RESET

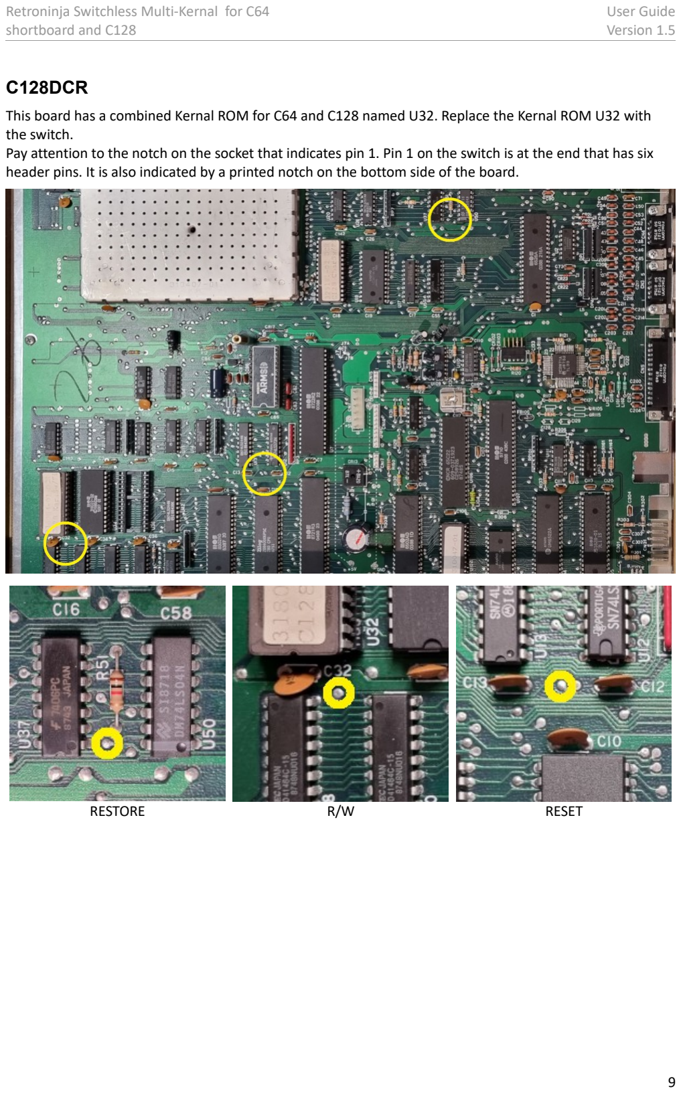
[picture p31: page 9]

C128DCR
This board has a combined Kernal ROM for C64 and C128 named U32. Replace the Kernal ROM U32 with the switch.
Pay attention to the notch on the socket that indicates pin 1. Pin 1 on the switch is at the end that has six header pins. It is also indicated by a printed notch on the bottom side of the board.
RESTORE | R/W | RESET

# Using the Kernal switch

Switching C64 and C128 Kernals
Hold the restore key for about three seconds until the kernal menu is activated. Once in menu you can use cursor up/down to move to the Kernal you want to switch to and press return. The switch resets the computer with the new Kernal and saves your choice for next power-on.

Switching C64 Kernal in a C128
When switching the C64 Kernal in a C128, hold the CBM and restore keys for about three seconds until the C64 kernal menu is activated. Keep holding the CBM key while selecting Kernal with the cursor up/down and return keys. While pressing return you should hold the CBM key until the reset is done to be taken to C64 mode. Otherwise you will end up in C128 mode after switching C64 Kernal and will have to do a GO64 or CBM+reset again.
The switch saves your choice for next power-on.

In the a C128DCR you can use either C128 kernal menu or C64 kernal menu to switch Kernal but both C64 Kernal and C128 Kernal will be switched at the same time.

# Upgrading the firmware

The firmware in the microcontroller can be upgraded using the 6-pin ISP header. The source code is written for Arduino and programming the firmware can be done directly from the Arduino IDE using an ISP programmer.
If your device is using an Atmega328 it can be programmed as an Arduino UNO. The other variants require custom board definitions. I recommend the DIY AVR cores that can be installed using the Arduino Boards Manager (https://github.com/sleemanj/optiboot).
If you can't or don't want to use Arduino there are some precompiled hex files for the Kernal switch and along with fuse configurations and syntax examples for how to program it using avrdude. These can be found under the Applications folder in my GitHub repository at: https://github.com/RetroNynjah/Switchless-Multi-ROM-for-27128-27256

# Programming the flash chip (ROM)

The flash chip needs to be programmed before soldering it. If you need to reprogram the flash later it must first be desoldered and then resoldered again after reprogramming.
The flash chip should contain the Mini-Kernal image followed by all switchable kernal images in correct order. All images needs to have a size of exactly 16KB.

C64
In a C64 switch those 16KB are made up of 8KB Basic + 8KB Kernal.

C128/C128D
In the C128 the C128 kernal is 16KB and it does not have to be paired with a Basic ROM. The C64 ROM in a C128 is the same as the one in a C64 so it needs basic+kernal pairs.

C128CR/C128DCR
In the C128CR/DCR the C128 kernal is 16KB and needs to be paired with the C64 Basic and C64 Kernal. As the switch will switch both C64 and C128 kernal at the same time you will have to pay extra attention to how you mix the images to not get a confusing setup.

# Document revision history

1.0 Initial version
1.1 Document title corrected
1.2 C128DCR pictures added and minor adjustments
1.3 Added information about Kernal ROM locations and sockets 1.4 Added information about R/W on C128
1.5 Expanded information about R/W problems on C128

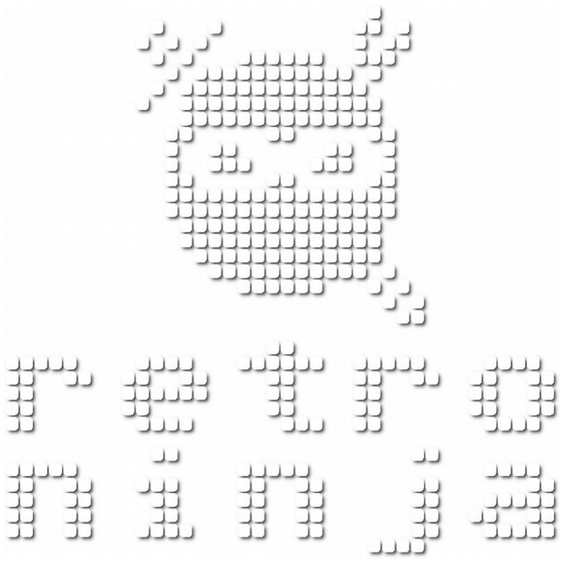
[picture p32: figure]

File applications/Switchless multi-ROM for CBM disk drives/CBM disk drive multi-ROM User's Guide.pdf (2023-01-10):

# Switchless Multi-ROM for CBM 1541-II, 1571 & 1581 User’s Guide

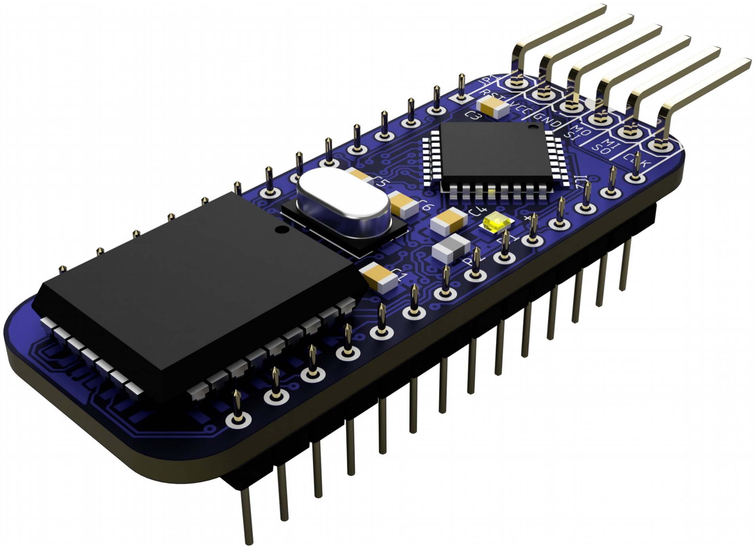
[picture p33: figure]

This microcontroller-based switchless ROM-switcher for the 1541-II, 1571 and 1581 disk drives lets you switch drive ROM between stock CBM DOS and JiffyDOS or other DOS version using simple basic commands. It's based on the switchless multi-ROM for 27128/27256 ROMs. Read more about it at: https://github.com/RetroNynjah/Switchless-Multi-ROM-for-27128-27256

## Usage

The switcher is listening to the data bus for a predefined word and a number. The easiest way to send the word to the drive is to issue a load command to the drive from basic with the word as filename or to utilize a JiffyDOS wedge command.
The default magic word is #@RNROM where # is the number of the ROM image you want to switch to.
LOAD “1@RNROM”,8 switches drive 8 to DOS image 1 and LOAD “2@RNROM”,8 switches to image 2 and so on. The default valid range of numbers is 1-4.
The drive will respond with a file not found error but the programmer will pick up the command, blink the multi-ROM LED to indicate which image was selected, switch the ROM by setting the high address pins accordingly and reset the drive using the newly selected ROM.
The selected ROM will be remembered and used at power-on.
If you have a JiffyDOS kernal in your computer you can select the right device using CTRL+D and issue the following commands instead: @1@RNROM or @2@RNROM
P a g e 1 | 5

Retroninja 1541-II switchless multi-ROM | User’s Guide version 1.2

## Theory of operation

At power on, the microcontroller in the ROM switcher reads address 0 from its internal EPROM to find out which ROM it should select, sets the address A14-A16 or A15-A16 on the flash chip depending on ROM size and then resets the drive to make sure it’s booted with the correct image. This can be noticed when the drive is powered on and the drive initializes and stops spinning and then spins up again briefly during the switch reset.
It then starts listening for a switch command.
Even at a clock speed of 20 MHz, reading and analyzing a 1-2MHz data bus can be a challenge so the data on the 1541-II data bus is buffered in the switch by a 74AHCT273 flip-flop that is clocked by the Write signal on the 6502 MPU in the disk drive. By clocking the data with the R/W signal we filter out irrelevant bus traffic and the flip-flop holds the data until the next write cycle. This gives the microcontroller enough time to read the data from the flip-flop.
The microcontroller listens for a predefined sequence of bytes in reverse order (MORNR@) and once the sequence is found, it treats the following numeric character as the target ROM image number. The reverse order of the characters on the bus is why the image number must be specified at the beginning of the command.
The microcontroller sets address pins A14-A16 or A15-A16 on the flash chip according to image selection and it stores the ROM number at address 0 of its internal EPROM for use at next power-on. It then resets the drive by toggling the IEC reset line.

## Building the circuit

The switcher is small and a bit difficult to solder but it can be hand soldered. The reason for the small size is space constraints in many disk drives such as the 1541-II, 1571 and 1581.
The Flash chip is the trickiest part to solder and I recommend reflow soldering of the top side using stencil and solder paste. Then solder the bottom side by hand and finally solder the pin headers.

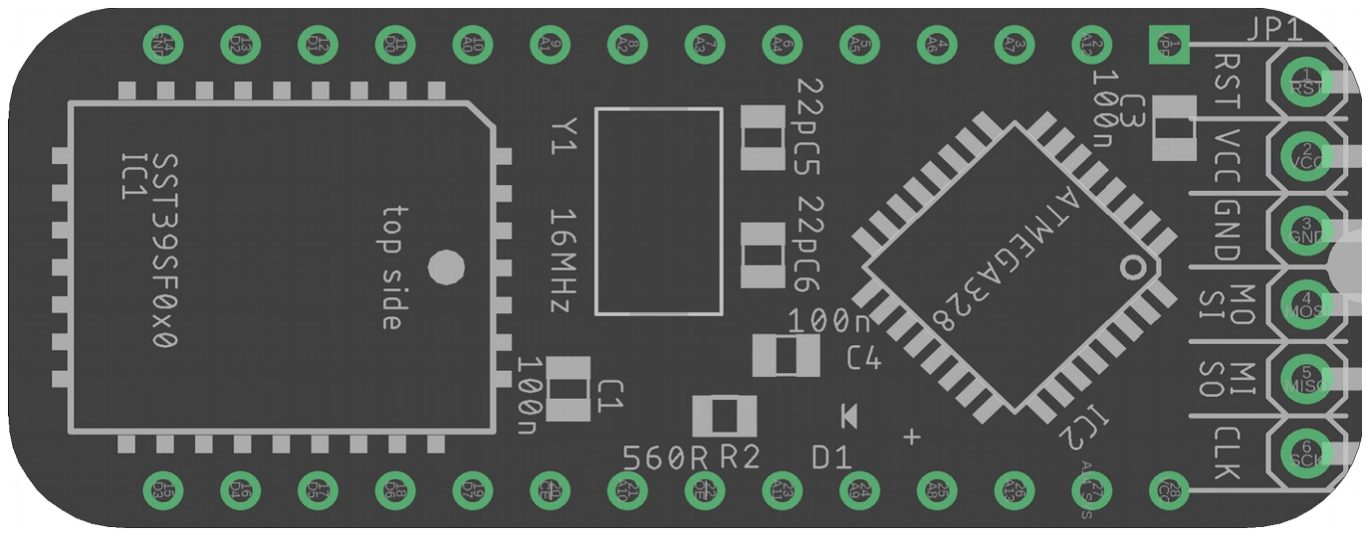
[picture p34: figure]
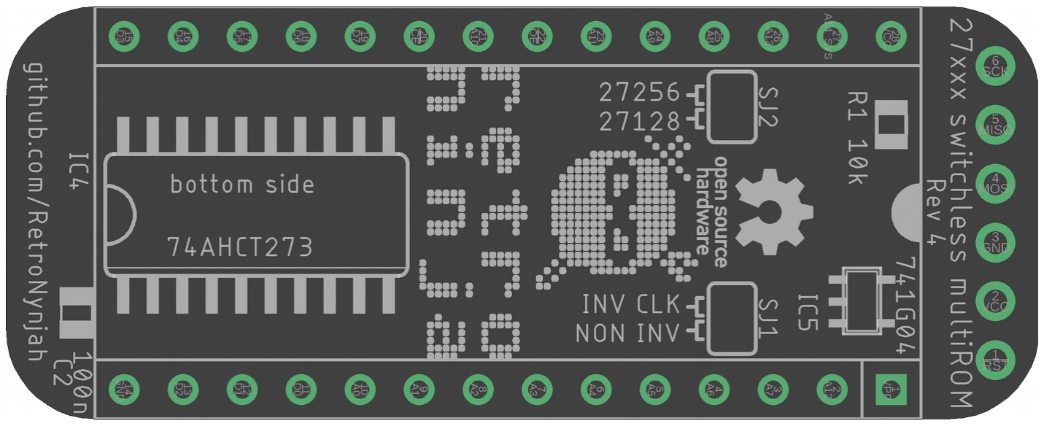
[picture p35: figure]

P a g e 2 | 5

### Parts

The switcher is designed for the SST39SF010A flash chip but the bigger SST39SF020/SST39SF040 could be used too if no SST39SF010A is available. Remember to duplicate the flash contents to fill all of flash to prevent floating pins from switching to empty flash areas.
The microcontroller can be pretty much any variation of ATmega48/88/168/328 as long as it can run at 20MHz.
The flip-flop needs to be a 74AHCT273. LS/HCT/AHC or any other variant will most likely not work. The 74AHCT1G04 single gate inverter is needed for inverting the active low write signal from the 6502 to the active high clock input of the flip-flop.
The recommended crystal is a 20 MHz crystal (for 1571/1581) but a 16MHz works for 1541-II.
The LED on the board is optional but flashes a number of times indicating the number of the selected ROM when switching. It is only there for debugging reasons.
The pin headers that goes into the ROM socket should have round machined pins or be of that long flat stackable type that is used for the pass-through pin headers on Arduino shields. The flat ones are recommended as the profile gets even lower with those headers. There is almost no headroom in the 1541-II, 1571 and 1581 external drives. The internal drives in the 128D models have more room. Square pin headers destroy the ROM socket in the drive so don't use those.

### Programming the microcontroller

The code for the controller was created using the Arduino environment and the device can be programmed in circuit from a sketch in the Arduino IDE using an ISP programmer.
I recommend the DIY AVR cores that can be installed using the Arduino Boards Manager (https://github.com/sleemanj/optiboot).
If you can't or don't want to use Arduino there are some precompiled hex files for the Kernal switch and along with fuse configurations and syntax examples for how to program it using avrdude. These can be found under the Applications folder in my GitHub repository at https://github.com/RetroNynjah/Switchless-Multi-ROM-for-27128-27256
How to use an Arduino as ISP or how to use an ISP programmer such as a USBASP will not covered by this document.
The firmware can also be programmed using AVRDUDE and the pre-compiled HEX file or using the popular TL866II programmer. The pin-out of the programming pins on the PCB matches the pin-out of the TL866II ICSP connector so a straight 6-pin cable can be used.

### Programming the flash chip

Due to space constraints, there are no on-board programming headers for the flash chip so the flash chip must be programmed in a flash/EPROM programmer before soldering it to the board or desoldered for reprogramming.
It could also be possible to make a programming adapter to put on top of the flash chip to program it while it’s still soldered to the board but this is not tested.
The ROM chip in the 1541-II is only 128 kbit (16 kilobyte) and the 1571/1581 drive ROMs are 256kbit (32 kilobyte) while the flash chip is 1 Mbit (128 kilobyte). It’s highly recommended to fill the entire flash chip with working DOS images to prevent bricking of the drive by selecting a non-existing image. The switcher will not work without a working ROM in the drive that can receive the serial data and
P a g e 3 | 5

put it on the data bus.
If you just use two ROM images, fill the flash with the same two images over and over for safety.

## Installation

The circuit can be installed in the drive without soldering by using DuPont cables with test clips that attaches to the R/W pin on the 6502 MPU and to the reset pin on the back of any of the IEC connectors. However, it is recommended to solder the cables to the pins on the bottom of the drive PCB. That makes for a much more robust and transportable solution.
An even more stable solution is to solder the cables to the edge of the switcher PCB instead of using a pin header but that could make it harder to upgrade the firmware in the future.
The edge of the Multi-ROM PCB with the six ISP pins should face the notched end of the ROM socket (Pin 1).

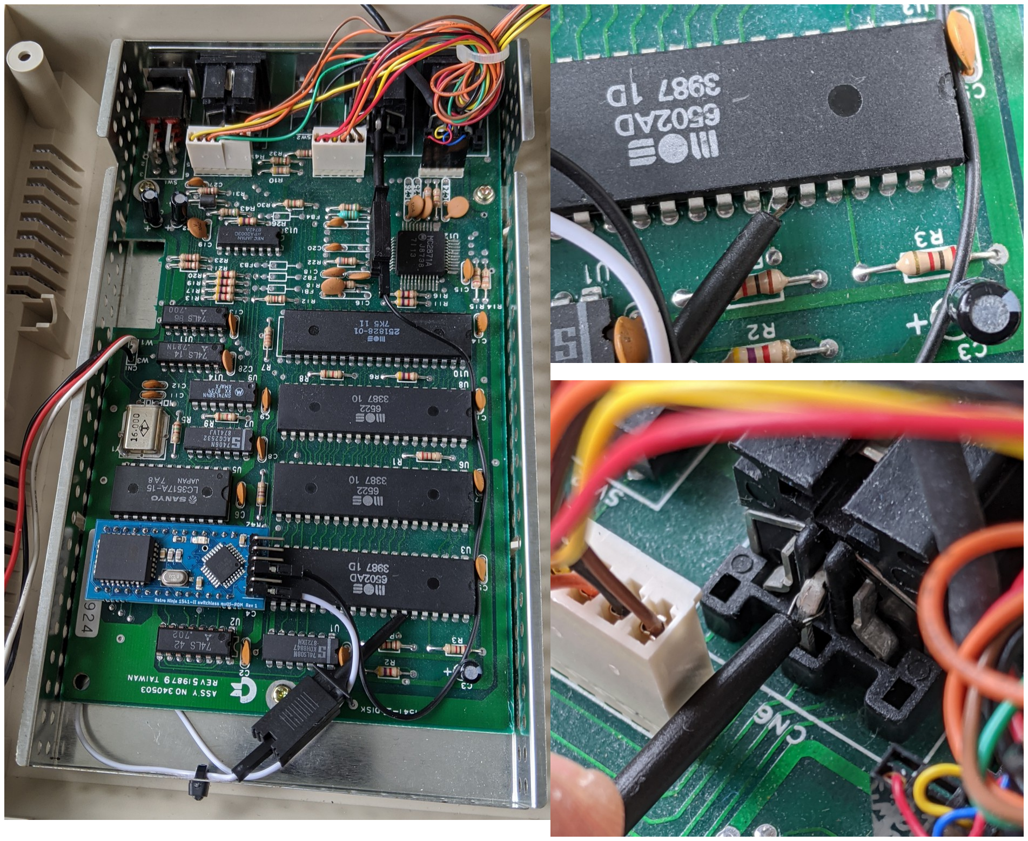
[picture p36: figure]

The clock signal (CLK on the Multi-ROM) connects to the R/W pin (pin 34) on the 6502 MPU.
MOSI on the Multi-ROM connects to IEC reset. That’s the center pin on the back of the IEC connectors. The Multi-ROM works without a connection to IEC reset but a manual drive reset would then be needed after switching ROM.
The sketch and a pre-compiled firmware for the Multi-ROM can be found in the Applications directory in the repository at:
https://github.com/RetroNynjah/Switchless-Multi-ROM-for-27128-27256
P a g e 4 | 5

## Troubleshooting

If the device becomes bricked due to an incorrect DOS image, program the ATmega with a sketch that sets byte 0 to 0x00 or 0xFF in the internal EPROM. Then upload the original Multi-ROM sketch again and you should be back on track.
You can also set byte 0 of the EEPROM to 0x00 using AVRDUDE or using the Minipro software. Switching will not work if you are some fast loaders such as Action Replay in your computer. Try switching the ROM without the fast loader. Switching ROM using JiffyDOS in the C64 is working fine though.
The switcher work in other CBM compatible drives that are using 27128 or 27256 ROMs. The Enhancer 2000 has been tested and works but unfortunately there's just not space enough in the OC-118 drive.

## Change history

This is the change history for the user’s guide.
For changes to the schematics, PCB or firmware, please refer to the GitHub repository at https://github.com/RetroNynjah/Switchless-Multi-ROM-for-27128-27256
Date | Version | Description
2021-05-15 | 1 | Initial version
2021-05-22 | 1.1 | Alternative ATmega MCUs
2023-01-10 | 1.2 | Major update. Now supports 1571/1581. Updated recommendations for crystals and microcontrollers

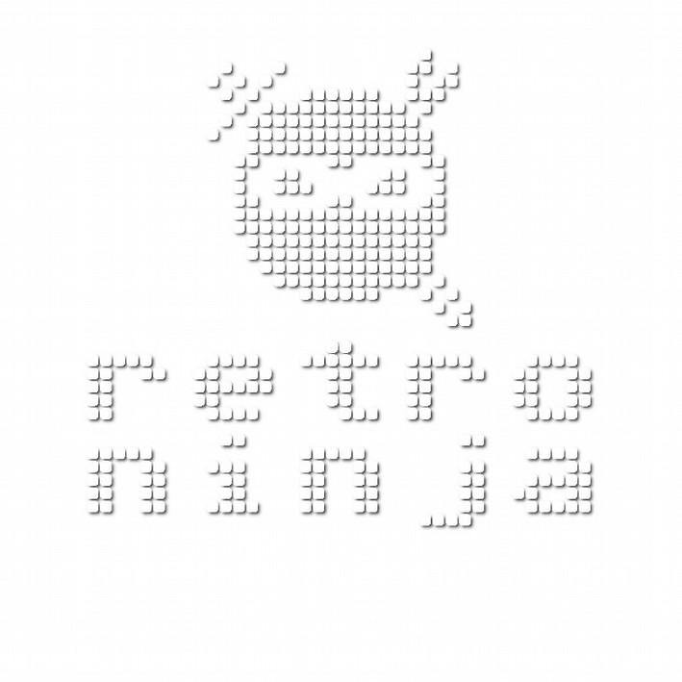
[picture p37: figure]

P a g e 5 | 5

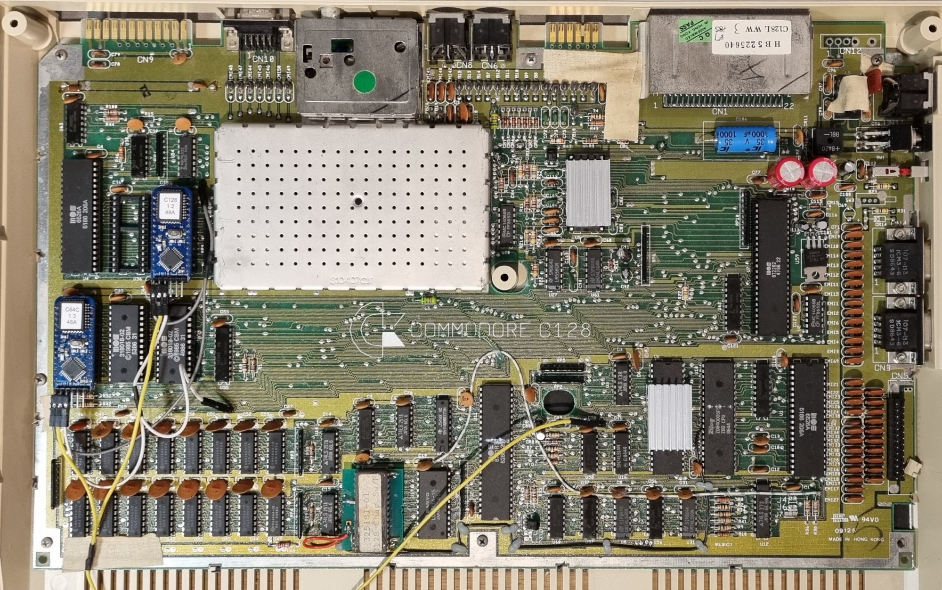
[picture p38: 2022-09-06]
applications/Switchless multi-kernal for C64 shortboard and C128/images/c128d_installation.jpg

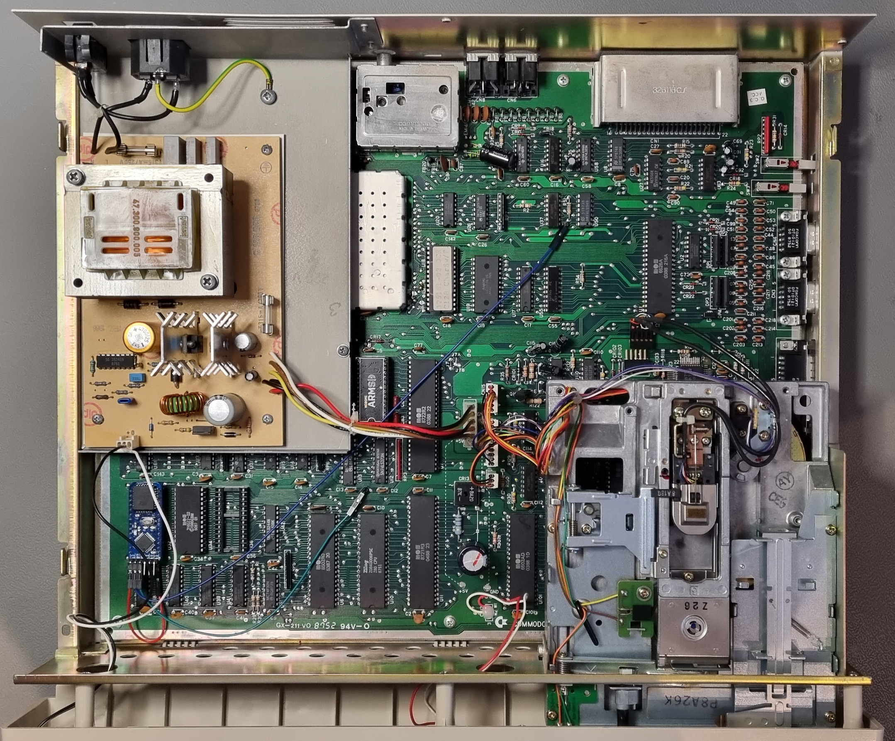
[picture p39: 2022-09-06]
applications/Switchless multi-kernal for C64 shortboard and C128/images/c128dcr_installation.jpg

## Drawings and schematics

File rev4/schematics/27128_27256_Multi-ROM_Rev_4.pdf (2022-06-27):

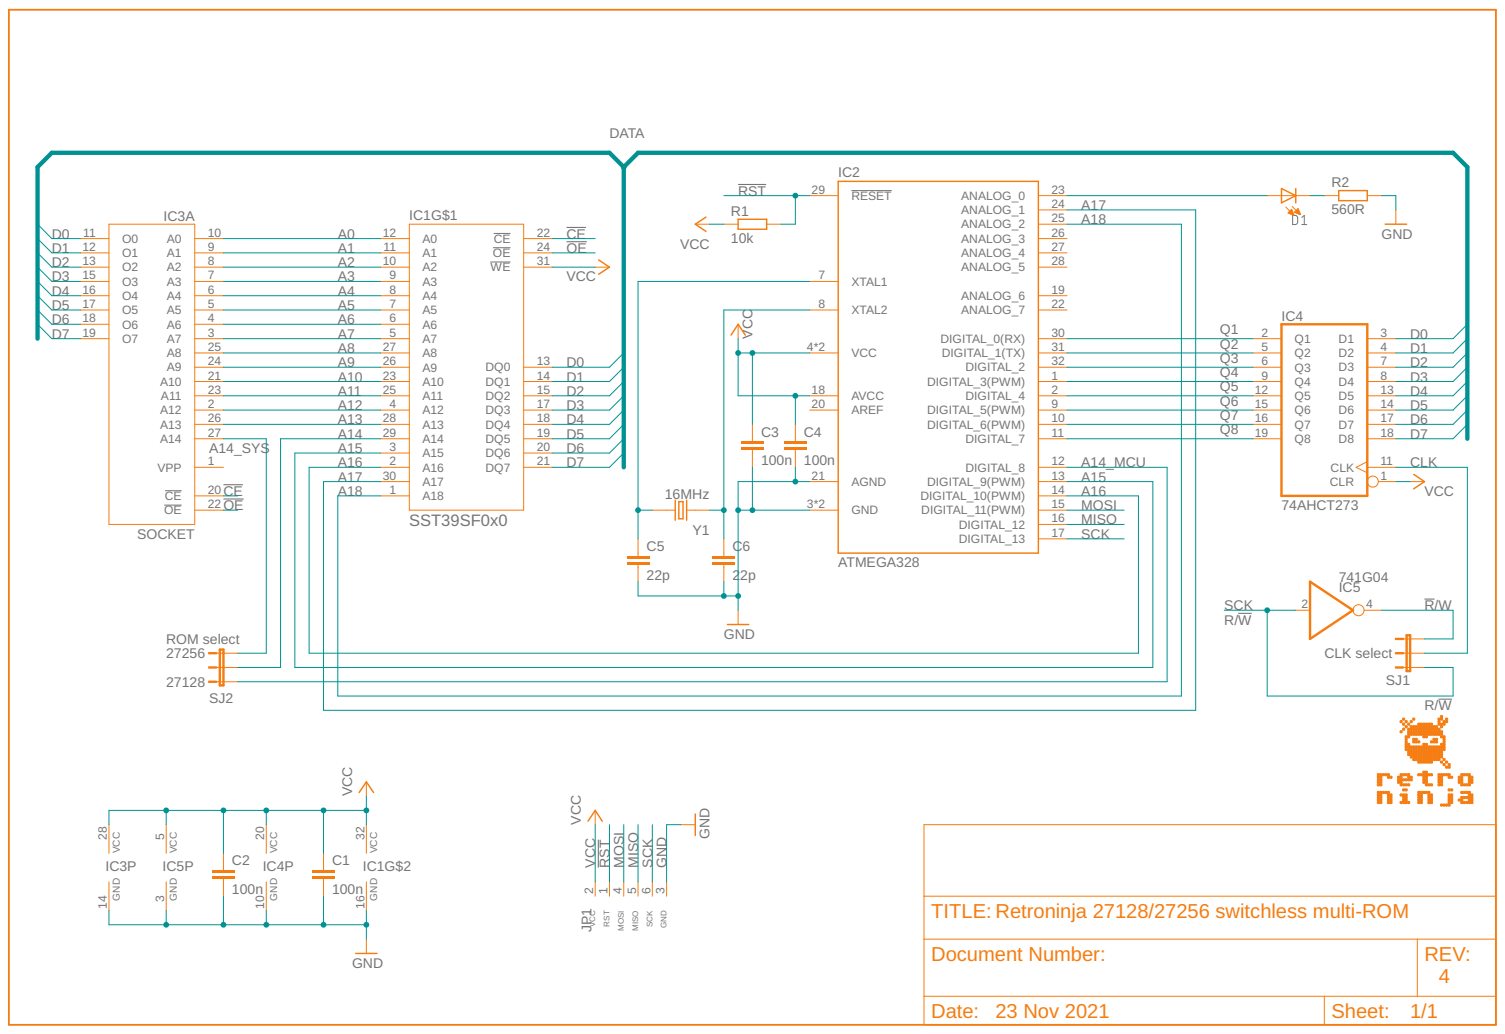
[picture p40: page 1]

Retroninja 27128/27256 switchless multi-ROM

SCK RST VCC MOSI GND

Document Number: | REV: 4

Date: 23 Nov 2021 | Sheet: 1/1

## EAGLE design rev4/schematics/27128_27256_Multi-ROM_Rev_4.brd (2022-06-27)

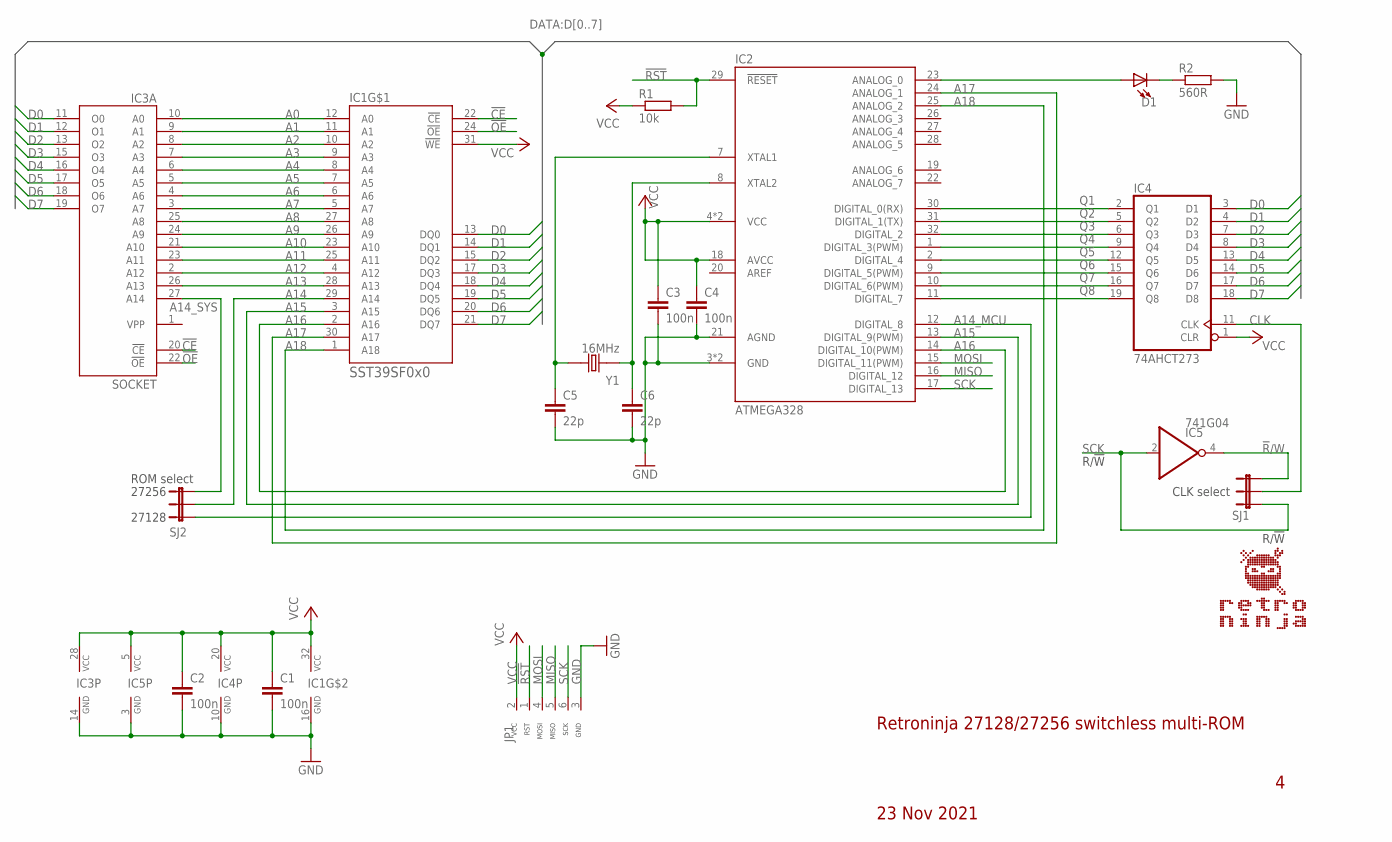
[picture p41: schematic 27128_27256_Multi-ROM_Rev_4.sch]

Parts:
C1, C2, C3, C4: 100n; C0805
C5, C6: 22p; C0805
D1: LED_0805; LED0805
IC1: SST39SF0x0; PLCC32_SHORT
IC2: ATMEGA328; TQFP32
IC3: SOCKET; DIL28-6_DOWNPINS
IC4: 74AHCT273; SO20
IC5: 741G04; SOT23-5
JP1: ICSP_CONNECTOR_TL866_RIGHT2; HEADER_1X6_RIGHT
R1: 10k; R0805
R2: 560R; R0805
SJ1, SJ2: JUMPER-3SJ; SJ-3
Y1: 16MHz; CRYSTAL_SMD-2_7X4X2.3

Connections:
!CE: IC1.22 (!CE), IC3.20 (!CE)
!OE: IC1.24 (!OE), IC3.22 (!OE)
!R!/W: IC5.4 (O), SJ1.3
!RST: IC2.29 (!RESET), JP1.1 (RST), R1.2
A0: IC1.12 (A0), IC3.10 (A0)
A1: IC1.11 (A1), IC3.9 (A1)
A2: IC1.10 (A2), IC3.8 (A2)
A3: IC1.9 (A3), IC3.7 (A3)
A4: IC1.8 (A4), IC3.6 (A4)
A5: IC1.7 (A5), IC3.5 (A5)
A6: IC1.6 (A6), IC3.4 (A6)
A7: IC1.5 (A7), IC3.3 (A7)
A8: IC1.27 (A8), IC3.25 (A8)
A9: IC1.26 (A9), IC3.24 (A9)
A10: IC1.23 (A10), IC3.21 (A10)
A11: IC1.25 (A11), IC3.23 (A11)
A12: IC1.4 (A12), IC3.2 (A12)
A13: IC1.28 (A13), IC3.26 (A13)
A14: IC1.29 (A14), SJ2.2
A14_MCU: IC2.12 (DIGITAL_8), SJ2.1
A14_SYS: IC3.27 (A14), SJ2.3
A15: IC1.3 (A15), IC2.13 (DIGITAL_9(PWM))
A16: IC1.2 (A16), IC2.14 (DIGITAL_10(PWM))
A17: IC1.30 (A17), IC2.24 (ANALOG_1)
A18: IC1.1 (A18), IC2.25 (ANALOG_2)
CLK: IC4.11 (CLK), SJ1.2
D0: IC1.13 (DQ0), IC3.11 (O0), IC4.3 (D1)
D1: IC1.14 (DQ1), IC3.12 (O1), IC4.4 (D2)
D2: IC1.15 (DQ2), IC3.13 (O2), IC4.7 (D3)
D3: IC1.17 (DQ3), IC3.15 (O3), IC4.8 (D4)
D4: IC1.18 (DQ4), IC3.16 (O4), IC4.13 (D5)
D5: IC1.19 (DQ5), IC3.17 (O5), IC4.14 (D6)
D6: IC1.20 (DQ6), IC3.18 (O6), IC4.17 (D7)
D7: IC1.21 (DQ7), IC3.19 (O7), IC4.18 (D8)
GND: C1.2, C2.2, C3.2, C4.2, C5.2, C6.2, IC1.16 (GND), IC2.3 (GND), IC2.5 (GND), IC2.21 (AGND), IC3.14 (GND), IC4.10 (GND), IC5.3 (GND), JP1.3 (GND), R2.2
MISO: IC2.16 (DIGITAL_12), JP1.5 (MISO)
MOSI: IC2.15 (DIGITAL_11(PWM)), JP1.4 (MOSI)
unnamed: C6.1, IC2.8 (XTAL2), Y1.1
unnamed: C5.1, IC2.7 (XTAL1), Y1.2
unnamed: D1.A, IC2.23 (ANALOG_0)
unnamed: D1.C, R2.1
Q1: IC2.30 (DIGITAL_0(RX)), IC4.2 (Q1)
Q2: IC2.31 (DIGITAL_1(TX)), IC4.5 (Q2)
Q3: IC2.32 (DIGITAL_2), IC4.6 (Q3)
Q4: IC2.1 (DIGITAL_3(PWM)), IC4.9 (Q4)
Q5: IC2.2 (DIGITAL_4), IC4.12 (Q5)
Q6: IC2.9 (DIGITAL_5(PWM)), IC4.15 (Q6)
Q7: IC2.10 (DIGITAL_6(PWM)), IC4.16 (Q7)
Q8: IC2.11 (DIGITAL_7), IC4.19 (Q8)
SCK: IC2.17 (DIGITAL_13), IC5.2 (I), JP1.6 (SCK), SJ1.1
VCC: C1.1, C2.1, C3.1, C4.1, IC1.31 (!WE), IC1.32 (VCC), IC2.4 (VCC), IC2.6 (VCC), IC2.18 (AVCC), IC3.28 (VCC), IC4.1 (CLR), IC4.20 (VCC), IC5.5 (VCC), JP1.2 (VCC), R1.1
VPP: IC3.1 (VPP)

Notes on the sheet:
Retroninja 27128/27256 switchless multi-ROM
23 Nov 2021
27128
27256
R/!W
CLK select
ROM select

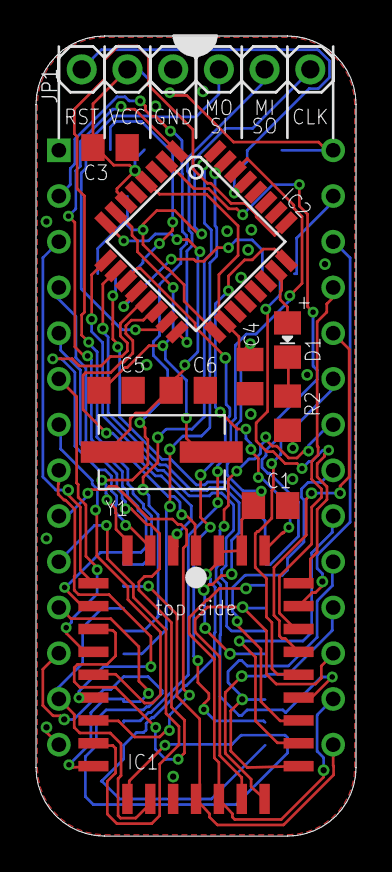
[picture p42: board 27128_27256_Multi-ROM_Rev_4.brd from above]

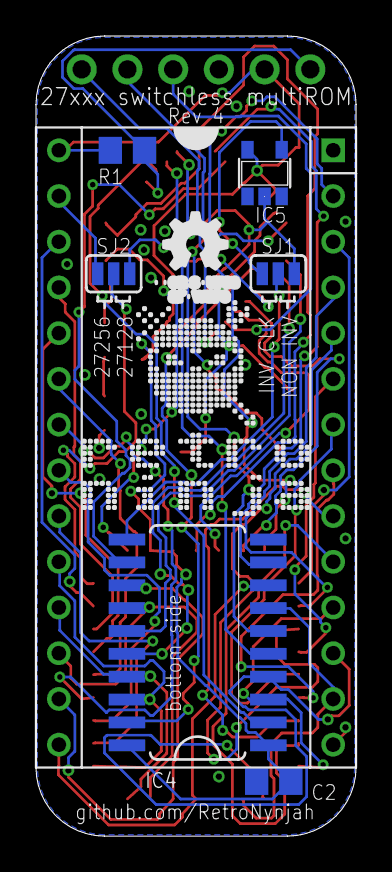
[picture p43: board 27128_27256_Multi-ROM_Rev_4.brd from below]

Board: 2 copper layers, 17.8 x 44.5 mm, 20 parts (8 on the bottom side), 51 nets.

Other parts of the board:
U$1: RETRONINJA_12MM
U$2: OSHW_5MM

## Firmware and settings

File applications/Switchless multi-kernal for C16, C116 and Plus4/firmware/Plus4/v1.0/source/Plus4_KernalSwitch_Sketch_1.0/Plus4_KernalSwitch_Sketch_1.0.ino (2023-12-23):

/*
#########################################################################################
#                                                                                       #
#  Kernal switcher sketch for Commodore Plus/4
#  To be used with the Retroninja 27128/27256 switchless multi-ROM in 27128 mode.       #
#                                                                                       #
#  Version 1.0                                                                          #
#  https://github.com/retronynjah                                                       #
#                                                                                       #
#########################################################################################
*/

#include <EEPROM.h>

// searchString is the command that the kernalselector firmware sends to the ROM switcher.
// Searchstring below is RNROM+4#
// The command will be followed by a single byte ROM number between 1 (0x01) and 15 (0x0f)
byte searchString[] = {0x52,0x4E,0x52,0x4F,0x4D,0x2b,0x34,0x23}; // "RNROM+4#"

// pin defitions
int resetPin = 11;
int clockPin = 13;
int ledPin = A0;

int savedROM;
int commandLength = sizeof(searchString);
int bytesCorrect = 0;
int blinkROM = 0;
bool ledstate = LOW;
long ledchange = 0;
volatile bool clockstate;
bool resetstate;
bool resetholding = false;
bool inmenu = false;
long resetpressed;

void pciSetup(byte pin) {
  // enable Pin Change Interrupt for requested pin
  *digitalPinToPCMSK(pin) |= bit(digitalPinToPCMSKbit(pin));  // enable pin
  PCIFR |= bit(digitalPinToPCICRbit(pin));                    // clear any outstanding interrupt
  PCICR |= bit(digitalPinToPCICRbit(pin));                    // enable interrupt for the group
}



ISR(PCINT0_vect)  // handle pin change interrupt for D8 to D13 here
{
  // read state of clock pin (D13)
  clockstate = PINB & B100000;
}


void cleareeprom() {
  for (int i = 0; i < EEPROM.length(); i++) {
    EEPROM.write(i, 0);
  }
}


void switchrom(int romnumber, bool doreset) {

  if (doreset) {
    // Hold reset low
    digitalWrite(resetPin, LOW);
    delay(100);
    pinMode(resetPin, OUTPUT);  // reset pin
    digitalWrite(resetPin, LOW);
  }

  // switch eprompin A14 (D8)
  if (romnumber & B00001) {
    digitalWrite(8, HIGH);
  } else {
    digitalWrite(8, LOW);
  }

  // switch eprompin A15 (D9)
  if (romnumber & B00010) {
    digitalWrite(9, HIGH);
  } else {
    digitalWrite(9, LOW);
  }

  // switch eprompin A16 (D10)
  if (romnumber & B00100) {
    digitalWrite(10, HIGH);
  } else {
    digitalWrite(10, LOW);
  }

  // switch eprompin A17 (A1)
  if (romnumber & B01000) {
    digitalWrite(A1, HIGH);
  } else {
    digitalWrite(A1, LOW);
  }

  // switch eprompin A18 (A2)
  if (romnumber & B10000) {
    digitalWrite(A2, HIGH);
  } else {
    digitalWrite(A2, LOW);
  }

  // if switching to a new kernal that isn't the menu kernal - save kernal to EEPROM address 0
  if ((romnumber != savedROM) && (romnumber != 0)) {
    EEPROM.write(0, romnumber);
    savedROM = romnumber;
  }

  if (romnumber != 0) {
    inmenu = false;
  }

  if (doreset) {
    // Release reset
    delay(200);
    pinMode(resetPin, INPUT_PULLUP);
  }

  // Give system some time to reset before entering main loop again.
  delay(500);
  blinkROM = romnumber;
}


void setup() {

  // set data pins 0..7 as inputs
  DDRD = B00000000;

  // Keep reset active (low) during setup
  digitalWrite(resetPin, LOW);
  pinMode(resetPin, OUTPUT);

  pinMode(clockPin, INPUT);

  pinMode(8, OUTPUT);   // eprom A14
  pinMode(9, OUTPUT);   // eprom A15
  pinMode(10, OUTPUT);  // eprom A16
  pinMode(A1, OUTPUT);  // eprom A17
  pinMode(A2, OUTPUT);  // eprom A18
  pinMode(ledPin, OUTPUT);

  digitalWrite(ledPin, LOW);

  // retrieve last used ROM from ATmega EEPROM and switch ROM using ROM address pins A14-A18
  savedROM = EEPROM.read(0);
  if (savedROM > 15) {
    savedROM = 0;
  }
  if (savedROM == 0) {
    inmenu = true;
  }

  switchrom(savedROM, false);
  
  // release reset
  pinMode(resetPin, INPUT_PULLUP);
  delay(500);  // Give system some time to reset before entering loop

  // Enable pin change interrupt on pin D13(PB5) connected to R/!W signal
  pciSetup(clockPin);
}


void loop() {

  if (inmenu) {
    ledstate = LOW;
    blinkROM = 0;
    // while in menu mode, listen for command
    if (clockstate == HIGH) {
      byte byteCurr = PIND;
      clockstate = LOW;
      if (bytesCorrect == commandLength) {
        // We have already found our command string. This byte must be the ROM number
        // Valid numbers are 1-15
        if ((byteCurr >= 1) && (byteCurr <= 15)) {
          // ROM number within valid range. Switch ROM and perform a reset
          switchrom(byteCurr, true);
        } else {
          bytesCorrect = 0;
        }
      }
      // We don't have full command string yet. Check if current byte is what we are looking for
      else if (byteCurr == searchString[bytesCorrect]) {
        // Increase bytesCorrect to check for next character
        bytesCorrect++;
      } else {
        bytesCorrect = 0;
      }
    }

  } else {
    // while not in menu mode, listen for reset
    resetstate = PINB & B001000;
    if (resetstate == LOW) {
      // reset pressed
      ledstate = HIGH;
      if (resetholding == false) {
        // start counting reset hold time
        resetpressed = millis();
        resetholding = true;
      }
      if ((millis() - resetpressed) > 2000) {
        // Switch to menu ROM and perform a reset
        inmenu = true;
        switchrom(0, true);
        ledstate = LOW;
        resetholding = false;
      }
    } else {
      // reset not held
      if (resetholding){
        // reset has just been released
        ledstate = LOW;
        resetholding = false;
      }
      
      //if kernal has just been switched we can do some led blinking now to indicate selected kernal
      if (blinkROM > 0) {
        if (ledchange == 0) {
          // first blink turn on LED and start counting
          ledstate = HIGH;
          ledchange = millis() + 50;
        } else {
          if (millis() > ledchange) {
            // time to toggle LED
            if (ledstate == HIGH) {
              ledstate = LOW;
              blinkROM--;
              if (blinkROM > 0) {
                // turn off LED and start counting
                ledchange = millis() + 250;
              } else {
                ledchange = 0;
              }
            } else {
              // turn on LED and start counting
              if (blinkROM > 0) {
                ledstate = HIGH;
                ledchange = millis() + 50;
              }
            }
          }
        }
      } 
    }
    digitalWrite(ledPin, ledstate);
  }
}

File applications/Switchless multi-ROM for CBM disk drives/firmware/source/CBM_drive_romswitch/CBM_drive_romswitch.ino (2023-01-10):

/*
#########################################################################################
#                                                                                       #
#  ROM switcher sketch for 1541-II, 1571, 1581 (28-pin ROM)                             #
#  To be used with the Retroninja 27128/27256 switchless multi-ROM in either            #
#  27128 or 27256 mode. Configure romsize below to match your use case                  #
#                                                                                       #
#  Version 1.2                                                                          #
#  https://github.com/retronynjah                                                       #
#                                                                                       #
#########################################################################################
*/

#include <EEPROM.h>

// searchString is the command that is used for switching ROM.
// It is passed by the 1541-II in reverse order so the variable should be reversed too.
// The command should be preceded by a ROM number between 1 and 4 when used.
// The below reversed searchString in hex ascii is MORNR@ which is specified like this on the C64: 1@RNROM, 2@RNROM and so on.
byte searchString[] = {0x4D,0x4F,0x52,0x4E,0x52,0x40};

// define size of ROM block to switch. Valid values are 128 or 256.
// rom images in flash m,ust match this size.
// 1541-II = 128
// 1571 = 256
// 1581 = 256
const int romsize = 128;

// pin defitions
int resetPin = 11;
int clockPin = 13;
int ledPin = A0;

int commandLength = sizeof(searchString);
int bytesCorrect = 0;
volatile bool state;
static byte byteCurr;

void pciSetup(byte pin)
{
    *digitalPinToPCMSK(pin) |= bit (digitalPinToPCMSKbit(pin));  // enable pin
    PCIFR  |= bit (digitalPinToPCICRbit(pin)); // clear any outstanding interrupt
    PCICR  |= bit (digitalPinToPCICRbit(pin)); // enable interrupt for the group
}



ISR (PCINT0_vect) // handle pin change interrupt for D8 to D13 here
{    
       // read state of pin 13
       state = PINB & B00100000;
}
 

void cleareeprom(){
  for (int i = 0 ; i < EEPROM.length() ; i++) {
    EEPROM.write(i, 0);
  }
}


void resetdrive(){

  digitalWrite(resetPin, LOW);
  pinMode(resetPin, OUTPUT);
  delay(50);
  digitalWrite(resetPin, HIGH);
  pinMode(resetPin, INPUT);

}


void switchrom(int romnumber){

  for (int x = 0; x <= romnumber; x++){
    digitalWrite (ledPin, HIGH);
    delay(30);
    digitalWrite (ledPin, LOW);
    delay(250);
  }
  delay (200);

  if (romsize == 128){
    // switch eprompin A14 (D8)
    if (romnumber & B01){
      digitalWrite(8 , HIGH);
    }  
    else {
      digitalWrite(8 , LOW);
    }
  
    // switch eprompin A15 (D9)
    if (romnumber & B10){
      digitalWrite(9 , HIGH);
    }  
    else {
      digitalWrite(9 , LOW);
    }
  }
  else if (romsize == 256){
    // switch eprompin A15 (D9)
    if (romnumber & B01){
      digitalWrite(9 , HIGH);
    }  
    else {
      digitalWrite(9 , LOW);
    }
  
    // switch eprompin A16 (D10)
    if (romnumber & B10){
      digitalWrite(10 , HIGH);
    }  
    else {
      digitalWrite(10 , LOW);
    }
  }

  int savedROM = EEPROM.read(0);
  if (savedROM != romnumber){
    EEPROM.write(0, romnumber);
  }
  resetdrive();
}


void setup() {

  // set data pins as inputs
  DDRD = B00000000;
  
  pinMode(13, INPUT); // clock pin
  pinMode(8, OUTPUT); // eprom A14. connection of A14 is controlled by solder jumper
  pinMode(9, OUTPUT); // eprom A15
  pinMode(10, OUTPUT); // eprom A16
  pinMode(A1, OUTPUT); // eprom A17
  pinMode(A2, OUTPUT); // eprom A18

  pinMode(clockPin, INPUT); // R/!W
  pinMode(resetPin, INPUT); // Keep reset pin as input while not performing reset.

  pinMode (ledPin, OUTPUT);

  // retrieve last used ROM from ATmega EEPROM and switch ROM using A14/A15
  int lastROM = EEPROM.read(0);
  if (lastROM > 4){
    cleareeprom();
    lastROM = 0;
  }
  switchrom(lastROM);
  
  // enable pin change interrupt on pin D13(PB5) connected to R/W on 6502
  pciSetup(clockPin); 
}


void loop() {
  if (state == HIGH){
    byteCurr = PIND;
    state=LOW;
      
    // we don't have full search string yet. check if current byte is what we are looking for
    if (byteCurr == searchString[bytesCorrect]){
      // It is the byte we're waiting for. increase byte counter
      bytesCorrect++;
	    if (bytesCorrect == commandLength){
        // we have our full search string. wait for next byte
		    while(state == LOW){}
    		byteCurr = PIND;
    		// This byte should be the ROM number
    		// valid numbers are 1-4 (ASCII 49-52)
    		if ((byteCurr >= 49)&&(byteCurr<=52)){
              // rom number within valid range. Switch rom
              switchrom(byteCurr - 49);
    		}
    		else if(byteCurr == searchString[0]){
              // it was the first byte in string, starting with new string
              bytesCorrect = 1;
    		}
        else{
          bytesCorrect = 0;
        }
  	  }
    }
    // byte isn't what we are looking for, is it the first byte in the string then?
    else if(byteCurr == searchString[0]){
        // it was the first byte in string, starting with new string
        bytesCorrect = 1;
    }
    else {
      // byte not correct at all. Start over from the beginning
      bytesCorrect = 0;
    }
  }
}

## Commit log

2022-06-27 Initial upload
    [27128_27256_Multi-ROM_Rev_4.brd, 27128_27256_Multi-ROM_Rev_4.sch]
2022-09-06 Kernal switch C128DCR support
    New mini-kernals that send different commands for C128DCR switches. C64/C128 mini-kernal version numbers aligned.
    Added C128DCR firmware v 1.2. version number aligned with C128 firmware.
    Updated Kernal switch user guide to version 1.2 with added C128DCR solder point locations.
2022-09-06 Updated Kernal switch pictures and corrected user guide version
2022-09-07 Updated Kernal switch user guide
    User Guide version 1.4 with added information about Kernal ROM locations and sockets.
2022-11-30 Mini-kernals version 1.5 and C128 firmware 1.2.1
    Minor change in keyboard detection to try and mitigate key bounce in mini-kernal (C64+C128)
    Minor correction in C128 firmware
    [constants.asm, main.asm]
2022-12-01 Recompiled firmware for C64 shortboard kernal switch
    Recompiled firmware using DIY AVR core
2023-01-03 Firmware v1.4 for C64 and C128 Kernal switches
    Version numbers aligned between firmware for different Kernal switches as functionality is the pretty much same for all switches.
    Improved handling of restore key functionality while in menu to prevent switches from going into reset loop while holding restore.
    Code cleanup and some optimizations of main loop.
    Thanks Pär Högberg!
    [C128DCR_KernalSwitch_Sketch_1.4.ino, C128_KernalSwitch_Sketch_1.4.ino, C64_shortboard_KernalSwitch_Sketch_1.4.ino]
2023-01-10 New firmware version with support for 1571/1581.
    Reworked and heavily optimized firmware for drive ROM switch to support 1571 and 1581 if using 20MHz crystal.
    Updated documentation to reflect this change.
    Rebranded from Switchless multi-ROM for 1541-II to Switchless multi-ROM for CBM disk drives now that it supports quite a lot more drives.
    Thanks to Pär Högberg for contributing code optimizations.
    [CBM_drive_romswitch.ino]
2023-01-10 Create readme.md
    Folder moved to applications/Switchless multi-ROM for CBM disk drives
2023-07-12 Updated C64 shortboard/C128 user guide
    Updated user guide to rev 1.5 with expanded information about R/W problems on some C128 boards.
2023-12-23 Plus/4 Kernal switch added to applications
    Updated technical guide and readme and added application directory for Plus/4 Kernal switch
2023-12-23 Update Retroninja Switchless Multi-ROM for 27128 & 27256 - Technical Guide Rev 1.3.pdf
2023-12-23 Update Retroninja Switchless Multi-Kernal for Commodore C16, C116 and Plus4 - User Guide Rev 1.0.pdf
